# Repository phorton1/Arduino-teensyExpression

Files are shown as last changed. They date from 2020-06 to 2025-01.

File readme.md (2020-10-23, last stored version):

# teensyExpression MIDI controller

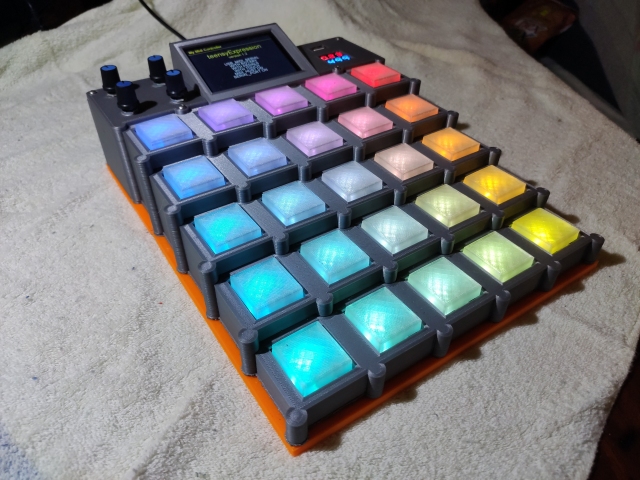
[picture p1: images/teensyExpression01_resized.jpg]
teensyExpression MIDI controller


This github repository describes and contains the source code and other materials
for a 3D printed, **teensy 3.6** based MIDI controller.  The controller has a 5x5 array
of switches, each with an individually adressable ws2812B colored LED,
four rotary controllers,
a 3.5" touchscreen,
inputs for four (4) standard 1/4" expression pedals, a 1/8" stereo jack used for a serial port, and the main USB type "A" connector,
a USB host port, and, lol, a volt/amp meter to monitor the USB power supply.

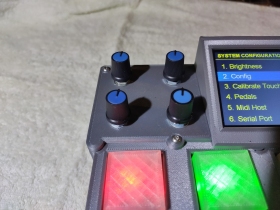
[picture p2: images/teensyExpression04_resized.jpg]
teensyExpression rotary controls

*four rotary controllers*

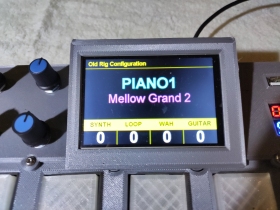
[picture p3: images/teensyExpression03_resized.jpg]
teensyExpression touch screen

*3.5" touchscreen*

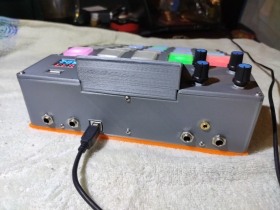
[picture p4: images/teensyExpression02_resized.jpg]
teensyExpression back panel

*inputs for four (4) standard 1/4" expression pedals, 1/8" stereo jack for serial port, and the main USB type "A" connector*

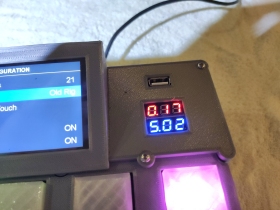
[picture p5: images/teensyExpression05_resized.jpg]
teensyExpression host port and amp-meter

*USB host port, and volt/amp meter on USB power supply*

It is intended to be a *foot* controller ... hence the tiered setup which makes it
easier to press buttons with your toes without having to reach over other buttons.
FWIW, I play the guitar barefooted, while sitting in a chair.

There are two major aspects to this project.  First there is the [**hardware**](hardware/), which is
relatively straight forward, and there are circuit diagrams, fusion 360 files, some
instructions, and so on that might allow someone to create a copy if they wanted to.

The second major aspect is the [**software**](design/). Inasmuch as this was conceived as BOTH an
experimental platform to let me mess with USB midi, and particularly the **Fishman FTP
Triple Play** dongle/controller, it also has been programmed to fit into my existing
performance setup.  For me, it is "gig ready", as well as a place I can try different
experiments with various things.

The software does not present itself as a general purpose, commercially viable,
consumer product.  Though that could be done, it is not my primary focus. So, while
I would be able to create, for example, a box on which the end user could map the
buttons to various MIDI CC control messages at "run time", that is not currently
implemented.

Because the entire thing can be (fairly) easily programmed from the Arduino IDE,
at this time I am selfishly doing whatever the heck I want in C++.   Some stuff
has been modularized and incorporated into things like a system configuration "preferences"
page, with persistent values stored in EEPROM, other stuff is "hard coded" into the C++, an
approach which limits the use of this by less technically saavy "consumer" or "nubie"
readers and potential users.

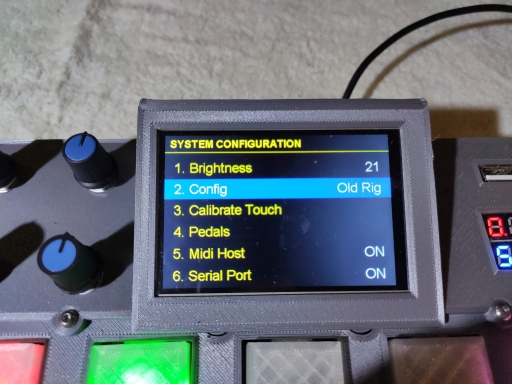
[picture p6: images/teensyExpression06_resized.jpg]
early preferences page


That's what it is.

There is still, in my opinion, considerable value in making this public, and so,
here, in spite of ongoing development, I am creating a public github
repository so that I can present it to you.

## THIS Repository Organization

The following subfolders are considered "public":

* [teensyExpression/](teensyExpression/) - contains the C++ source code,
  including the main INO file (teensyExpression.ino) and the C++ and H files
  needed to build the program.
* [design/](design/) - contains a description of the software architecture,
  with ideas on how other programmers might extend it, along with a
  description of the [User Interface](design/readme_ui.md) in it's
  current incarnation, including the [songMachine](design/readme_songmachine.md)
* [hardware/](hardware/) - contains the basic schematic, circuit diagrams,
  and information about building the electronics portion of the project.
* [ftp/](ftp/) - contains separate discussions and documents regarding
   my reverse engineering efforts on the FTP Triple Play dongle and controller

There are a number of other sub-folders which are considered "private" for my own
personal use, and/or which exist only to support the readme.md files in the this
and the above subfolders:

* **images** - contains images used on this and various readme pages
* **junk** - contains a variety of weird files, images, doc files, that, for me, pertain
      to the design of the project, but which are not meant to be necessrily useful
      for a reader or anyone besides myself.
* **tests** - contains a number of test programs that are not necessarily currently up-to-date
    or useful.  I keep these for posterities sake as they may have snippets of code I will
    need in the future.

### 3D Printing Information

There is a separate repository containing the Fusion 360, STL, and gcode files
for this project that were used to 3D print the box and buttons.

* [fusion/](https://github.com/phorton1/Arduino-teensyExpression-fusion) - contains the STL, fusion 360 files, and notes on how to print and assemble the box

### Please See

This teensyExpression pedal is intimately involved with my long term ongoing
**[rPi bare metal vGuitar rig](https://hackaday.io/project/165696-rpi-bare-metal-vguitar-rig)**
project at hackaday.

In that process I have developed a number of other repositories which might be of interest
to audio system development hackers, including:

* **[circle](https://github.com/phorton1/circle)** - my fork of a a C++ bare metal rPi
development framework
* **[circle-prh](https://github.com/phorton1/circle-prh)** - my extensions to Circle, including
a port of the **Teensy Audio Library** to rPi bare metal, and an Arduino like development
approach.
* **[Loooper](https://github.com/phorton1/circle-prh-apps-Looper)** - a bare metal rPi based **Audio Looper**
including a 3D printed case with a 7" touchscreen, which hooks up to, and is controlled by,
this teensyExpression pedal.

### Notes on Building and GitHub **DEPENDENCIES**

This project relies on the teensyDuino installation.

It also depends on a number of Arduino libraries that must be manually placed in your
Arduino/libraries folder.  There is one small library that I wrote (myDebug.h and myDebug.cpp),
that I generally use in my Arduino programs, and is common to more than one of my published projects.

In addition there are several libraries that are publicly available, but unchanged by me
(ILI9341_t3 and ILI9341_fonts), which I have forked into my github account for ease in finding them,
and to provide me with a stable known "snapshot" of those libraries.

And finally there are some libraries that are publicly available, but to which I
have made modifications to, small or large, in order to get them to work in this project
(Paul's USBHost_t36 and my_LCDWIKI_*).

Each of these libraries is available as a github project here in my account, with a
name that is formatted like "Arduino-libraries-NameOfLibrary".   **These libraries
should be "cloned" or otherwise copied into your Arduino/libraries folder**.  Once
you have done that, you may rename them to remove the "Arduino-libraries" portion,
just leaving the NameOfLibrary portion in the directory structure if you wish.

* [myDebug](https://github.com/phorton1/Arduino-libraries-myDebug) -
   A debugging output library common to my Arduino projects, it contains
   global methods with names like "display" and "display_bytes" which are called
   throughout my code, and which can be turned on or off via defines.

* [base64](https://github.com/phorton1/Arduino-libraries-base64) -
  UNMODIFIED fork of Adam Rudd's https://github.com/adamvr/arduino-base64 repository

* [ILI9341_t3](https://github.com/phorton1/Arduino-libraries-ILI9341_t3) and
  [ILI9341_fonts](https://github.com/phorton1/Arduino-libraries-ILI9341_fonts) -
  These are UNMODIFIED versions of Paul's ILI9341 libraries, forked from
  his repository on 2020-10-03.   My program *may* compile and work with
  more current versions that he makes available at https://github.com/PaulStoffregen/ILI9341_t3
  and https://github.com/PaulStoffregen/ILI9341_fonts, but these forks are
  known to compile and work properly with my code.

* [USBHost_t36](https://github.com/phorton1/Arduino-libraries-USBHost_t36) -
  A slightly MODIFIED version of Paul's USBHost_t36 library, forked
  from https://github.com/PaulStoffregen/USBHost_t36 on 2020-10-03.
  The API was changed to make a few functions virtual and to expose
  a few private variables as "protected".

* [SdFat](https://github.com/phorton1/Arduino-libraries-SdFat) -
  A fork of Bill Greiman's https://github.com/greiman/SdFat with one slight
  modification - to increase BUSY_TIMEOUT_MICROS from 500000 to 1000000,
  which fixed problems I was having opening an SD card on a fresh boot.

* [my_LCDWIKI_GUI](https://github.com/phorton1/Arduino-libraries-my_LCDWIKI_GUI),
  [my_LCDWIKI_KBV](https://github.com/phorton1/Arduino-libraries-my_LCDWIKI_KBV), and
  [my_LCDWIKI_TouchScreen](https://github.com/phorton1/Arduino-libraries-my_LCDWIKI_TouchScreen) -
  These repositories contain the rude and crude port of the LCDWIKI Arduino libraries
  to the Teensy for the cheap touch screen I ended up using.  The touch screen
  is an 8 bit parellel port screen that looks like this:

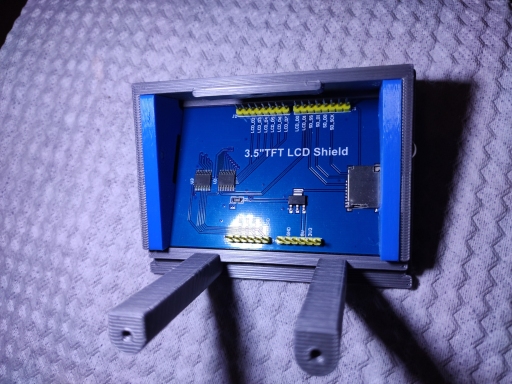
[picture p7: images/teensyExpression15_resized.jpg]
touchscreen holder
  

When I started working on this project, I started off using a different, much
faster and more teensy compatible 2.8" SPI touch screen.  One night I burned it, and
because I did not want to wait 6 weeks for a replacement (I live on a remote
island in the tropics) I was forced to go to a slower speed 8 bit parallel
Arduino touch screen ... which in turn required me to port the LCDWIKI library
for it to the teensy 3.6, which I did.

# Credits

Pretty much everything I do has been tremendously influenced by, and is more or less a direct
result of the work done by **Paul Stoffregen** and his wonderful **teensy** series of MPU boards.

Please visit his website at [prjc.com](https://www.prjc.com) and support him by purchasing teensy
boards and teensy related parts and accessories.    He also has github, hackaday, and facebook pages
that you can find easily on the internet. The man's a giant to me, and has forged important new
ground not only with the boards he makes, but also with the **vast** amount of open source
software he has created, not the least of which includes the ws2812 and ili9431 libraries, but
also his audio library, and well, what can you say ... so much more!

Also thanks to the many folks who have contributed to the [lcdwiki](http://www.lcdwiki.com) project.
Though I can't name them by name, many are the times when I have visited their website and utilized
their code.

That's it!

Thanks for checking this out!

Updated October 2020 - Patrick

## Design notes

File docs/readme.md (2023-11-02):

# teensyExpression MIDI controller



This github repository describes and contains the source code and other materials
for a 3D printed, **teensy 3.6** based MIDI controller.  The controller has a 5x5 array
of switches, each with an individually adressable ws2812B colored LED,
four rotary controllers,
a 3.5" touchscreen,
inputs for four (4) standard 1/4" expression pedals, a 1/8" stereo jack used for a serial port, and the main USB type "A" connector,
a USB host port, and, lol, a volt/amp meter to monitor the USB power supply.


*four rotary controllers*


*3.5" touchscreen*


*inputs for four (4) standard 1/4" expression pedals, 1/8" stereo jack for serial port, and the main USB type "A" connector*


*USB host port, and volt/amp meter on USB power supply*

It is intended to be a *foot* controller ... hence the tiered setup which makes it
easier to press buttons with your toes without having to reach over other buttons.
FWIW, I play the guitar barefooted, while sitting in a chair.

There are two major aspects to this project.  First there is the [**hardware**](hardware.md), which is
relatively straight forward, and there are circuit diagrams, fusion 360 files, some
instructions, and so on that might allow someone to create a copy if they wanted to.

The second major aspect is the [**software**](design.md). Inasmuch as this was conceived as BOTH an
experimental platform to let me mess with USB midi, and particularly the **Fishman FTP
Triple Play** dongle/controller, it also has been programmed to fit into my existing
performance setup.  For me, it is "gig ready", as well as a place I can try different
experiments with various things.

The software does not present itself as a general purpose, commercially viable,
consumer product.  Though that could be done, it is not my primary focus. So, while
I would be able to create, for example, a box on which the end user could map the
buttons to various MIDI CC control messages at "run time", that is not currently
implemented.

Because the entire thing can be (fairly) easily programmed from the Arduino IDE,
at this time I am selfishly doing whatever the heck I want in C++.   Some stuff
has been modularized and incorporated into things like a system configuration "preferences"
page, with persistent values stored in EEPROM, other stuff is "hard coded" into the C++, an
approach which limits the use of this by less technically saavy "consumer" or "nubie"
readers and potential users.



That's what it is.

There is still, in my opinion, considerable value in making this public, and so,
here, in spite of ongoing development, I am creating a public github
repository so that I can present it to you.

## THIS Repository Organization

TODO: rework this whole section

This repository contains the C++ source code,
  including the main INO file (teensyExpression.ino) and the C++ and H files
  needed to build the program.

There are a number of other sub-folders which are considered "private" for my own
personal use, and/or which exist only to support the readme.md files in the this
and the above subfolders:

* **images** - contains images used on this and various readme pages
* **junk** - contains a variety of weird files, images, doc files, that, for me, pertain
      to the design of the project, but which are not meant to be necessrily useful
      for a reader or anyone besides myself.
* **tests** - contains a number of test programs that are not necessarily currently up-to-date
    or useful.  I keep these for posterities sake as they may have snippets of code I will
    need in the future.

### 3D Printing Information

There is a separate repository containing the Fusion 360, STL, and gcode files
for this project that were used to 3D print the box and buttons.

TODO: rework

### Please See

This teensyExpression pedal is intimately involved with my long term ongoing
**[rPi bare metal vGuitar rig](https://hackaday.io/project/165696-rpi-bare-metal-vguitar-rig)**
project at hackaday.

In that process I have developed a number of other repositories which might be of interest
to audio system development hackers, including:

* **[circle](https://github.com/phorton1/circle)** - my fork of a a C++ bare metal rPi
development framework
* **[circle-prh](https://github.com/phorton1/circle-prh)** - my extensions to Circle, including
a port of the **Teensy Audio Library** to rPi bare metal, and an Arduino like development
approach.
* **[Loooper](https://github.com/phorton1/circle-prh-apps-Looper)** - a bare metal rPi based **Audio Looper**
including a 3D printed case with a 7" touchscreen, which hooks up to, and is controlled by,
this teensyExpression pedal.

### Notes on Building and GitHub **DEPENDENCIES**

This project relies on the teensyDuino installation.

It also depends on a number of Arduino libraries that must be manually placed in your
Arduino/libraries folder.  There is one small library that I wrote (myDebug.h and myDebug.cpp),
that I generally use in my Arduino programs, and is common to more than one of my published projects.

In addition there are several libraries that are publicly available, but unchanged by me
(ILI9341_t3 and ILI9341_fonts), which I have forked into my github account for ease in finding them,
and to provide me with a stable known "snapshot" of those libraries.

And finally there are some libraries that are publicly available, but to which I
have made modifications to, small or large, in order to get them to work in this project
(Paul's USBHost_t36 and my_LCDWIKI_*).

Each of these libraries is available as a github project here in my account, with a
name that is formatted like "Arduino-libraries-NameOfLibrary".   **These libraries
should be "cloned" or otherwise copied into your Arduino/libraries folder**.  Once
you have done that, you may rename them to remove the "Arduino-libraries" portion,
just leaving the NameOfLibrary portion in the directory structure if you wish.

* [myDebug](https://github.com/phorton1/Arduino-libraries-myDebug) -
   A debugging output library common to my Arduino projects, it contains
   global methods with names like "display" and "display_bytes" which are called
   throughout my code, and which can be turned on or off via defines.

TODO: cleanup NEEDS vs USES forked libraries

* **base64** -
  UNMODIFIED fork of Adam Rudd's https://github.com/adamvr/arduino-base64 repository
* [ILI9341_t3](https://github.com/phorton1/Arduino-libraries-ILI9341_t3) and
  [ILI9341_fonts](https://github.com/phorton1/Arduino-libraries-ILI9341_fonts) -
  These are UNMODIFIED versions of Paul's ILI9341 libraries, forked from
  his repository on 2020-10-03.   My program *may* compile and work with
  more current versions that he makes available at https://github.com/PaulStoffregen/ILI9341_t3
  and https://github.com/PaulStoffregen/ILI9341_fonts, but these forks are
  known to compile and work properly with my code.

* [USBHost_t36](https://github.com/phorton1/Arduino-libraries-USBHost_t36) -
  A slightly MODIFIED version of Paul's USBHost_t36 library, forked
  from https://github.com/PaulStoffregen/USBHost_t36 on 2020-10-03.
  The API was changed to make a few functions virtual and to expose
  a few private variables as "protected".

* [SdFat](https://github.com/phorton1/Arduino-libraries-SdFat) -
  A fork of Bill Greiman's https://github.com/greiman/SdFat with one slight
  modification - to increase BUSY_TIMEOUT_MICROS from 500000 to 1000000,
  which fixed problems I was having opening an SD card on a fresh boot.

* [my_LCDWIKI_GUI](https://github.com/phorton1/Arduino-libraries-my_LCDWIKI_GUI),
  [my_LCDWIKI_KBV](https://github.com/phorton1/Arduino-libraries-my_LCDWIKI_KBV), and
  [my_LCDWIKI_TouchScreen](https://github.com/phorton1/Arduino-libraries-my_LCDWIKI_TouchScreen) -
  These repositories contain the rude and crude port of the LCDWIKI Arduino libraries
  to the Teensy for the cheap touch screen I ended up using.  The touch screen
  is an 8 bit parellel port screen that looks like this:

  

When I started working on this project, I started off using a different, much
faster and more teensy compatible 2.8" SPI touch screen.  One night I burned it, and
because I did not want to wait 6 weeks for a replacement (I live on a remote
island in the tropics) I was forced to go to a slower speed 8 bit parallel
Arduino touch screen ... which in turn required me to port the LCDWIKI library
for it to the teensy 3.6, which I did.

# Credits

Pretty much everything I do has been tremendously influenced by, and is more or less a direct
result of the work done by **Paul Stoffregen** and his wonderful **teensy** series of MPU boards.

Please visit his website at [prjc.com](https://www.prjc.com) and support him by purchasing teensy
boards and teensy related parts and accessories.    He also has github, hackaday, and facebook pages
that you can find easily on the internet. The man's a giant to me, and has forged important new
ground not only with the boards he makes, but also with the **vast** amount of open source
software he has created, not the least of which includes the ws2812 and ili9431 libraries, but
also his audio library, and well, what can you say ... so much more!

Also thanks to the many folks who have contributed to the [lcdwiki](http://www.lcdwiki.com) project.
Though I can't name them by name, many are the times when I have visited their website and utilized
their code.

That's it!

Thanks for checking this out!

Updated October 2020 - Patrick

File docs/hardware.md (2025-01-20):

# Hardware (Electronics)

This subfolder contains the basic electrical circuit details used
in building the teensyExpression Box.

Physically, the most demanding task was to build the **switch array**, with 25 little
circuit boards, and 25 LED's to connect together in a grid.  Each LED is connected into
a series by 3 wires ... in two directions ... ground, 5V, and data in / data out from the
first, to the last LED.  A single 3 pin connector connects all 25 LED's to the teensy
(motherboard) and power supply.

The switch harness, overlayed on top of LED serial connections, consists of the 25
buttons connected (soldered) together into a 5x5 grid that presents itself
as two 5 pin connectors to the *motherboard*.

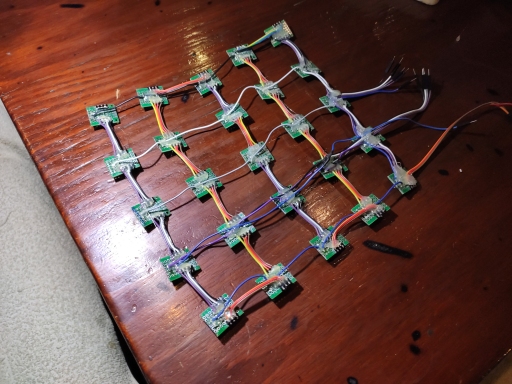
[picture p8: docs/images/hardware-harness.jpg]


The **motherboard** is a 70x50 mm prototype board that has a socket (two rows
of female header strips) into which a teensy 3.6 is plugged,
and which has connectors (female header strips) for the LEDs, switches,
rotary controls, serial port, TFT LCD display. The host USB port connector
is on the teensy 3.6 board itself.

Virtually every pin on the teensy was used in this
exersize, at the sacrifice of future expandability, but the gain of simplicity in the
circuit design.  Previous design iterations had used IO multiplexer chips, for example,
to communicate with the swtich array, via 4 pins, instead of 10, but in the end I just
decided to let the teensy handle all 10 pins from the switch array in favor of a simpler
electronic circuit.

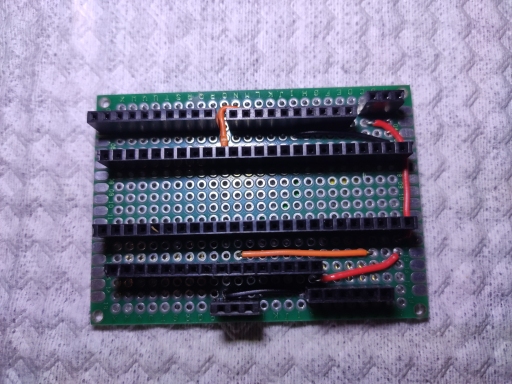
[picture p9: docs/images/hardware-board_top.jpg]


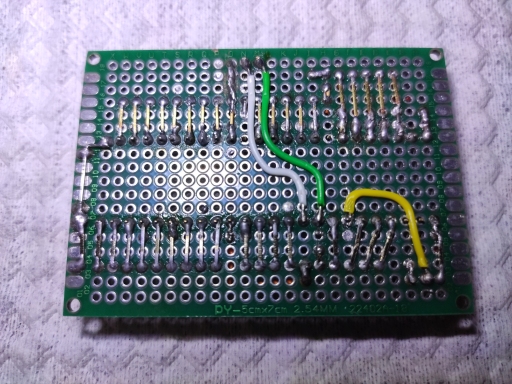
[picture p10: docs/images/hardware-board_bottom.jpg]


The TFT/touchscreen is connected to the motherboard through two 8 pin connectors.

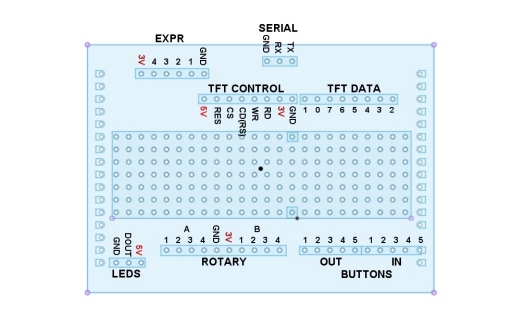
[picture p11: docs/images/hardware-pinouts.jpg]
hardware-pinouts,jpg

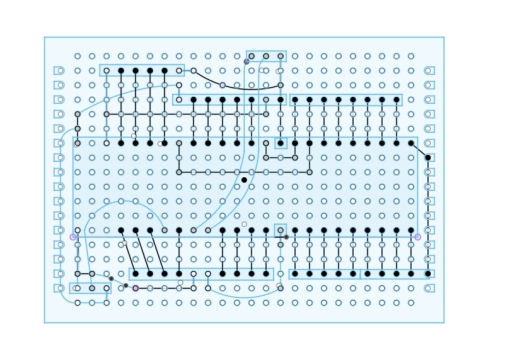
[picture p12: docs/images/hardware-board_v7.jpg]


Besides those three main components, there are separate subassemblies
and/or circuit boards for the four **rotary countrollers**,
the **USB port and amp-meter**, the **serial port connector**, and, finally,
the back panel with it's **four expression pedal 1/4" stereo jack inputs**.

There is a general overall sybolic schematic for this project.
You can click on the image below to see the PDF file.

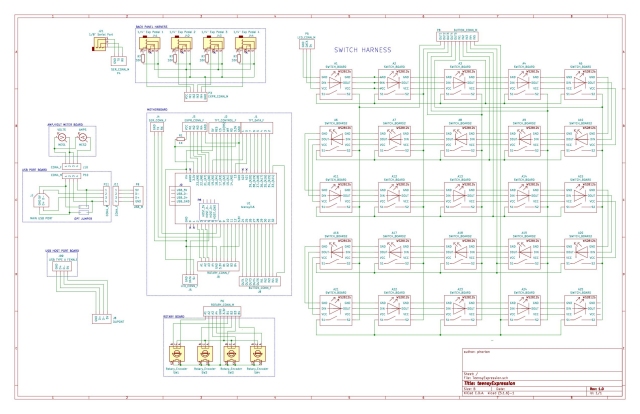
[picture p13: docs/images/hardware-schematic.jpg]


## LED/Switch Array

Each switch array circuit board contains a swtich and a ws2812b addressable LED.
The LEDs are wired back together with three wires between each one, in a series,
starting from the top left position, row-wise, back and forth, so the last LED
is at the bottom right.

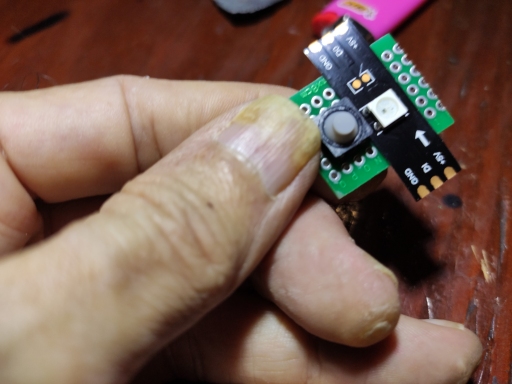
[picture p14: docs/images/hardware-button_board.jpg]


I cut the 25 ws2812 LED's from an inexpensive light strip that can be had for
as little $2, with shipping, on ebay.

The strip I used has 30 LEDs, with 30mm spacing, and with capacitors on about
every 8th LED. So one small strip was sufficient to make the box.

The switch circuit boards were cut to 20x25 mm from commonly available
20x80mm prototype boards that cost about 60 cents each on ebay.  I bought
them as part of a pack which included some other sizes for something
like $8.   With care 3 of switch-boards can be cut from each prototype board,
and, since 25 are needed, you'd need 9 of the prototype boards to reproduce
this project.

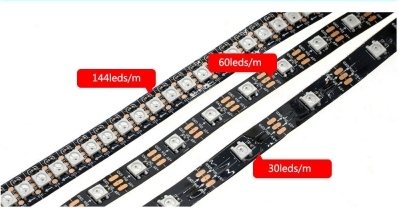
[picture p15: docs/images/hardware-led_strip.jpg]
(https://www.ebay.com/itm/383642094481)

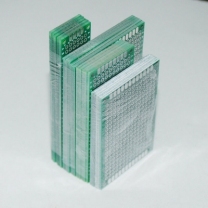
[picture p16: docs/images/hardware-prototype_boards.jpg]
(https://www.ebay.com/itm/252520067657)


*click on images above to see them in ebay*

I had already decided to make the buttons have a 45 mm spacing, a little larger,
and with a little more space than the drum pads on an akai MPD218 (typical
midi drumpad device).   The LED strips have a 30 mm spacing ... and so, after some
consternation ... I opted for the demanding task of cutting the strip apart and
then soldering it back together.

I tried to uniformely distribute the LED capacitors throughout the harness.

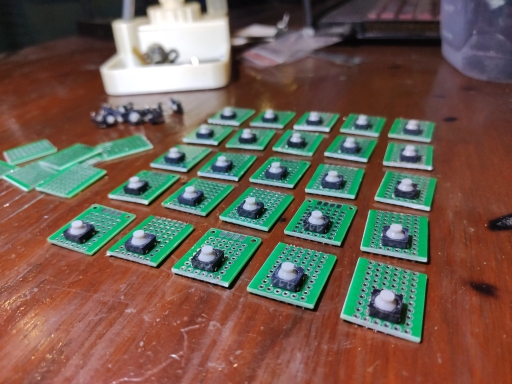
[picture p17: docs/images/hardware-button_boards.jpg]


The switches are soft silicon with momentary contacts.  They seemed to provide
enough spring back to work, and they work fine in practice.   I found them
available on ebay for $1.85 for 20 (so you'd need two packs, but have 15 left
over at the end).

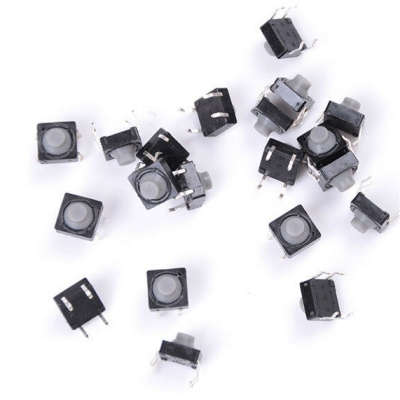
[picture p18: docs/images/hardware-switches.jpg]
(https://www.ebay.com/itm/313082729862)


*click on image above to see in ebay*

To complete the circuit boards I put a drop of super glue on the back of each
LED piece, held it on the circuit board, and bent the connectors around to the
back, trying to keep it as close as possible (centered) to the switch, which
occupies a 2x3 footprint on the board.

The switches are wired together in an array, with columns connnected to one pin of
each switch and rows connected the other pin of each switch.  Rows start at the
top and go down, and columns start at the left and go to the right.  These wires
end in two connectors which are called OUT (columns) and IN (rows) which plug
directly into the motherboard.  If you get em backwards, you merely have to change
the IN and OUT defines in the source code.

## Mother Board

The circuitry on the **motherboard** is pretty simple.  Most of it was
connected by using female headers with long leads and bending the leads
and connecting direclty to another header.

Here are two diagrams that show, respectively, the wiring for the back,
and the front of the circuit board.   The solid lines are made either
by bending leads and soldering them, or by running beads of solder
over multiple holes in the prototype board. The lighter blue lines
are wires that are soldered from one point to another.

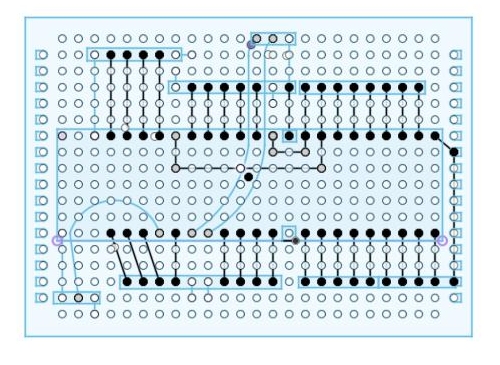
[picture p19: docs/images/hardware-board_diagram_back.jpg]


*above, motherboard back (as seen from the front)*

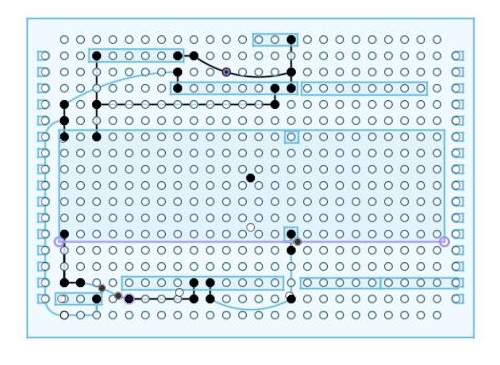
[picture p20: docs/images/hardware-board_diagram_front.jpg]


*above, motherboard front*

## TFT Touch Screen

The Touchscreen is connected directly to the motherboard by two 8 pin
dupont female to male cables.



The pinouts are detailed in previous diagrams.

## Rotary Encoders

I didn't take any pictures, or keep any detailed design description of the
Rotary Encoder board I threw together. So I would have
to open the box up and disassmble it to present it properly.

I am not using the momentary switches on the rotary encoders.
They were kind of an afterthought, and I had no more pins available on
the teensy by that point in the hack/implementation.

As I remember, I did not put any resistors or capacitors on it, I just wired
the ground to the ground pin for the momentary switch (don't even think it'sda
used), the 3.3V to the center pin on the rotary part of the things (the side with
three pins), and the pairs of connectors (IN and OUT) to the left, and right
pins on that side of the things.

If you get it wrong you merely have to change the definitions of the IN
and OUT pins in the source code.

## USB Port and Amp Meter

During earlier prototyping, and in general, I was curious about the power
consumption of the device, and so had taken to using an inexpensive USB
power meter to monitor the power usage.

These power meters are available on Ebay for about $7.

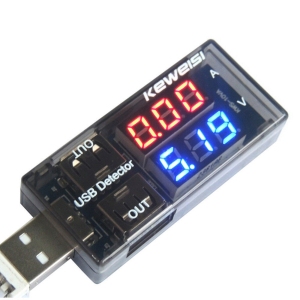
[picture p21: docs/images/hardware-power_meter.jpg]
(https://www.ebay.com/itm/401708239662)


*click on the image to go to ebay*

I merely desoldered the USB connectors, and connected the ground and 5V from
the main input USB typeB port to it, and ran it back to the micro-usb connnector
that connects to the teensy.

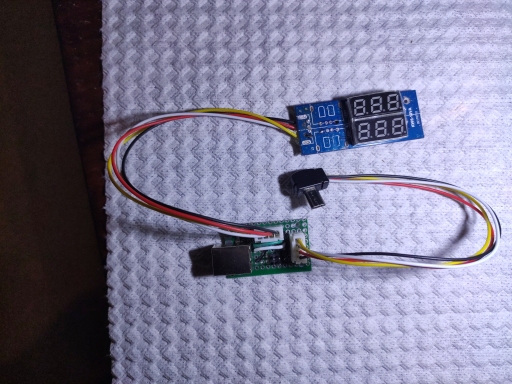
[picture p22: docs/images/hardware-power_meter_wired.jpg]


I was very pleased with these little micro-usb connectors that I also got
on ebay, at 10 for $5.79 (about 60 cents each)

And I needed the female TypeB connector as well (probably around $1 on ebay).

What made this step considerably more fun, and easy, was the purchase of some
prewired headers and sockets for 2.54mm circuit boards.  I got 10 of em for
under $4 on ebay, and used to two in this project.  I will definitely use these
more in the future, as I **hate** dupont connectors and trying to build them
from scratch!

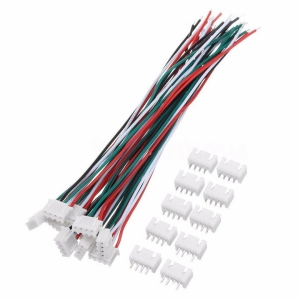
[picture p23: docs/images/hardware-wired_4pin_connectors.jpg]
(https://www.ebay.com/itm/264781666854)


The circuit board  is approximately 24x38 mm, and the typeB USB connector
projects about 3mm through the back of the box.

But it's really simple.  Basically it connects the typeB female usb port ground and 5V
to an outgoing pair on the connector that goes to the power meter, and the incoming pair
that comes back and is connected to the ground and 5V pins on the outgoing (to
the teensy) micro-usb connector.

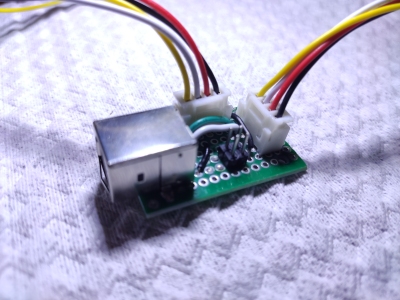
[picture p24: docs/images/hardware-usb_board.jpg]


The D- and D+ pins from the typeB connector are wired directly to the
output connector, and I added a jumper so that, if I want, I can remove
the USB meter and jumper the 5V and ground directly from the input typeB
socket to the output micro-usb connector.

Sorry about the lack of detail here! I am writing this *after* I finished
the hardware aspects of the project, but I think you can figure out how
it goes from this, and other standard information available on the web
about USB connectors.

## Serial Port Connector

The serial port connector is merely a 1/8" stereo jack connected
to a 3 pin dupont connector.   The *tip* of the connector is the
RX into the teensy, the *ring* is the TX from the the teensy, and
the *sleeve* is the ground.

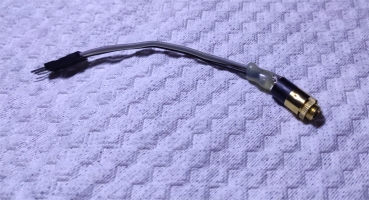
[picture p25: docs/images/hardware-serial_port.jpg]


The female, gold plated, 1/8 stero jack was about $1.50 on ebay.

## Host Port USB connector/board

The host port USB connector board is another 24x20 mm piece of one of the
20x80 prototype boards, with a micro USB female connector at one end, and
a 4 pin dupont connector at the other, that connects to a 4 pin header
soldered onto the teensy 3.6 board.

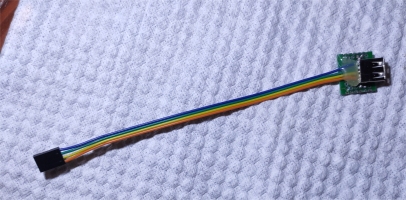
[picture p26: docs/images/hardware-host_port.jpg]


The female micro USB connectors are about 30 cents each, when purchased in
lots of 10 on ebay.

## Back Panel and 1/4" Expression Jacks

That leaves the back panel and the four 1/4" expression jacks.

I attached these to the 3D printed back and soldered the wires on in place so-as
to get appropriate lengths of wire with a minimum of fuss.   They are wired with
ground going to the *sleeve* of each connector, 3.3V going to the *ring*, and
the return "sense" pin wired to the *tip*.   The jacks were probably about $1
each on ebay.

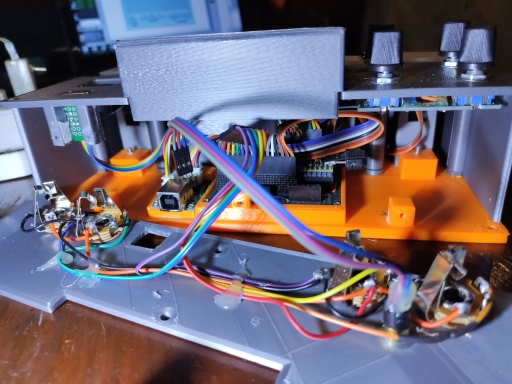
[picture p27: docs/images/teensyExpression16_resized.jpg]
putting it together1


After I put it together, I ran into some problems with this part of the build.
Notably, that when you would plug a 1/4" jack into the the things, it would
momentarily short the 3.3V to ground, yikes, rebooting the system.

It is not a good idea to short the 3.3V output from the voltage regulator
on the teensy directly to ground!

Yet I think the connectors are actually designed to avoid doing that by the spacing
of the tip and ring parts of the male vs the contact points of the female jacks.

The final solution was that I put a 1K resistor on the motherboard between the
3.3V output from the teensy and the common 3.3V connectors (*rings*) on the
connectors.   Although that works, by limiting the current that can flow in
the event of a short circuit, it should not have been necessary and I am
still thinking about how to do it correctly (next time!).

# Cost of Electronics Summary

So, as a curiousity, after the fact, I have tallied up the following costs for the
electronics part of the build.   Clearly the most expensive items is the teensy 3.6,
which I got WITH pins from  at: [prjc.com](https://www.pjrc.com/store/teensy36_pins.html).
They are currently $33.25.  Some of the other costs are just estimates, but I think its
pretty close.

| item | price |
|---|---|
| Teensy 3.6 pins |  $33.25 |
| USB Power Meter | $7.00 |
| 3.5" Touch Screen |  $5.00 |
| 30 x LED ws2812b strip | $2.00 |
| 25 x push buttons | $2.50 |
| 4 x Rotary Encoder | $4.00 |
| 4 x 1/4" female jacks | $5.00 |
| 1/8" female jack | $1.25 |
| female micro USB connector | $0.50 |
| mother prototype board | $2.50 |
| rotary encoder prototype board | $2.50 |
| 10 x small prototype boards | $10.00 (max) |
| Wired connectors and jacks | $1.00 |
| 5 x 40 pin female headers | $2.50 |
| Wired Dupont Connectors | $4.00 (max) |
| Other Wire | $1.00 |
| Solder, etc | $1.50 |
| **Total** | approx **$85.50** |

It was my goal to try to keep the cost of the project at, about, or under **$100**.
If I figure I used about 1kg of plastic in 3D printing it, at $20/kg,
then, I came close. This box could theoretically be built by anyone with a
3D printer for about $110.

Though I doubt anyone will take my exact design and replicate it, apart
from wanting the box itself, I wanted to prove that it could be made on
a budget, if one is willing to put the effort into it.

Also note that you could eliminate stuff (like the rotary encoders
and the usb power meter) in order to cut the costs a bit. I don't
actually envision using the rotary controllers that much as it is
a floor based *foot* pedal.

For me it is replacing a $270 Softstep II, a $100 akai MPD218, and
a $170 audio-front expression-to-usb-midi convertor, or nearly $600
of gear ... and three separate devices ... with one consolidated
usb midi device, so in addition to cost factors, for me it also reduces
the complexity of my rig, and the setup and teardown times thereof.

It also provides me with much more flexibility to do what I want, and
have not even yet envisioned, going forward.  More on that in the
software section of the project.

I have not seen any comparable hardware that sells for less than $200.
In fact, a box similar to this would probably retail in the $400-$500
price range, and some go for as much as $1500 to $2000.
I couldn't find what I wanted in the way of a foot controller
for running the FTP in conjunction with SampleTank and Tonestack
on Audiobus, on an iPad, so I built this.

Of course, it took several weeks of 3D design work, prototyping, and
nearly 2 full 40 hour weeks for me just to consctruct the final prototype.
And I'll probably be working on the software for months, or mabye years, more.
Nonetheless, it *might* be something that a typically impoverished musician could
put together.

So, with that, I conclude the "hardware" portion of our show!

Thanks,

**Patrick**

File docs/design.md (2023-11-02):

# Design (Software Architcture)

This page describes the software architecture for the teensyExpression ino
program.

For a discussion of the user interface (the "user manual"), please see
the [User Interface](ui.md) readme file.

For a discussion of the advanced automation features of the device,
please see the [songMachine](songmachine.md) readme file.

## Basic Architecture

The system can be viewed as a series of "layers", generally increasing in level
of abstraction as you move up the following diagram:

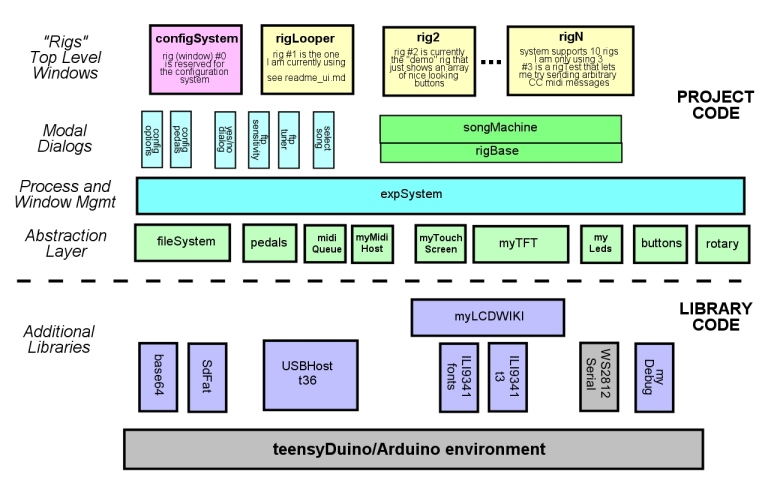
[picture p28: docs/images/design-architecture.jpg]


Everything above the dashed line, the **Project Code**, can be found in this repository.

Everything below the dashed line is in the *Arduino/libraries* folder (blue boxes) in
separate repositories available on my github page, and linked to from the main readme.md
file, or are (grey boxes) part of the basic **teensyDuino/Arduino** development environment
and easily available for public download.

Above the dashed line, the *teensyExpression* code, is organized somewhat as
follows.  There are a number of APIs (classes, objects) that represent an
**abstraction layer** of common functionality that are generally available to
higher layers.   This includes

- an abstraction of the SD Card FAT32 **fileSystem**.  The file system
  has it's own readme file at [filesystem.md](filesystem.md).
- an object that manages the four expression **pedals**
  including polling them and their functional behavior
- objects to process, and monitor **MIDI** io, including a
  *queue*, and handling both the main teensyDuino *USB midi* port,
  as well as the teensy 3.6 *midiHost* port
- a thin layer of abstraction of the **TouchScreen** and **TFT** display devices
- management of the ws2812 **LEDs**
- an object to manage and work with the 5x5 array of **buttons**
- an object to manage the **rotary controllers**

Above that, the **expSystem** is the main active object in the system.
It initializes all of the subsystems and does the bulk of event management,
in one of three ways: either by being called directly from the
teensyExpression.ino loop() method, or via one of two timer
interrupts:

- **updateUI()** is called directly from the main INO *loop()* method.
  This is the "UI thread" and is not considered time critical. All
  redrawing of the screen, and most updating of the LED colors,
  as well as certain processing of non-critical events happens
  in updateUI().
- **criticalTimerHandler()** is called up to 1000 times per second
  and handles the most time critical task, which is to
  transfer incoming midi from the midi-host port to the main USB
  midi port as rapidly as possible for live peformance.
  It also generally enqueues all midi
  messages for further processing and toggles the midi-activity
  indicator states for re-display in *updateUI()*.
- **timerHandler()** is called up to 200 times per second and
  does the bulk of the work in the system, including calling
  methods to poll the *pedals* and *buttons*, process the *serial
  ports* for incoming serial midi or file system traffic, and
  to process the *midiQueue* for midi monitoring and (FTP and
  external Looper) state changes.

Above the expSystem you have the main **Top Level Windows"** in
the system, which I call **"rigs"**.  There can only be one currently
active "rig" at a time, and those windows ALSO can implement
virtual versions of the *updateUI()*, *criticalTimerHandler(),* and
*timerHandler()* methods as they see fit.

Top Level Windows also get abstracted events from the expSystem
via the following virtual method calls:

- virtual bool **onRotaryEvent**(int num, int val)
- virtual void **onButtonEvent**(int row, int col, int event)
- virtual void **onSerialMidiEvent**(int cc_num, int value)

We will discuss **Rigs (Top Level Windows)** in more detail, below.

Finally, the expSystem manages various **modal dialog windows** that
can be popped (stacked) up over a given Top Level window.  Modal dialogs
can (and do) reprogram the buttons and LED colors as they see fit.
These modal windows include, at least conceptually, the following:

- **configOptions**, though not really windows, these are abstractions of
   configurable options that have a UI, and are stored as "preferences"
   (prefs.h) in EEPROM, and are managed by the **configSystem** (rig #0).
- **winConfigPedal** is a modal dialog that lets you edit the configuration
   of one of the four expression pedals, setting the basic *pedal type*,
   and within that one of three *curve types*, and the *curve points*
   that make up the curves.

The above are ONLY used by the configSystem.
The following are available for general use withing Rigs:

- **yesNoDialog** is a general purpose dialog to ask a question and get
  a yes/no (0/1) response.
- **winFtpSensitivity** is a modal dialog that allows you to display
  and adjust the sensitivity of the Fishman Triple Play pickup.
- **winFtpTuner** is a modal dialog that implements a guitar tuner
  using the Fishman Triple Play pickup.  It shows a "live" guitar
  fretboard, and typical guitar tuner UI.
- **winSelectSong** is a modal dialog that lets you choose, and/or
  view a **song file** which will run in the **songMachine**.
  The songMachine will also be discussed in more detail below,
  and in a separate readme file.

## Rigs (Top Level Windows)

The idea behind **"rigs"** is that you can have completely different setups,
that can do completely different things, with completely different user
interfaces and behaviors.

I have, in the past, used Rigs to differentiate, for instance, between
a tested, and gig ready piece of code, and another in-progress experimental
approach to some given hardware.

As currently checked-in (implemented) **I am only making use of one
actual functioning "rig"**.  I call this the **"LooperRig"** (*rigLooper.h
and cpp*), and it will provide the basic example, and documentation,
of "how the teensyExpression works" at this time.

The checked in source code *DOES* include two other "rigs".  One is
a **"demo" rig** that does nothing more than set all 25 leds to a nice
set of colors (as seen in the main photos of the pedal), and the other
is a vestigial piece of code, a **"test" rig**, that I created at one point
to allow me to send arbitrary MIDI CC messages and values to devices
for testing purposes.

Finally, it is important to note that the **"configSystem"** that
lets you modify, and retain settings through re-boots via "preferences"
stored in EEPROM, is implemented as rig #0, and so **rig number (0)
is reserved** and there is some special handling in expSystem.cpp
related to it, namely that *the top right button of every rig is
automatically set by the expSystem to "go to" the configuration
system (rig 0) on a **LONG CLICK***.

Apart from that, a rig "takes over" all of the buttons, LED display
characteristics, most of the display, and can have any arbitrarily
defined behavior.

## configurationSystem and rigLooper

A description of the user interface of these two rigs, which
currently pretty much constitutes the entire user interface at
this time can be found in the [User Interface](ui.md) readme file.

## songMachine and rigBase

The main Looper Rig (rigLooper.h and cpp) derives from **rigBase**.
Top Level windows that derive from *rigBase* can interact with,
and be driven by the **songMachine**.

The *songMachine* is an interpreter that takes text files that
describe a state machine that can be used to further automate
and orchestrate complicated tasks.

For example, the Looper Rig is capable of allowing you to
choose, in real time, a given *Synthesizer patch* vis one
set of buttons, or to turn a given *guitar effect* on or off
via another set of buttons, and/or *control the looper*
via a third set of buttons.

So, in a typical example, you might select the "Bass"
synthesizer patch with one button, turn the guitar down
and the synthesizer up with the pedals, and then press
a button to trigger a loop to start recording.

In this *"realtime"* mode of using the pedal, it can turn
out that you spend all your time **looking at your feet!**
And that there are **complex** series of buttons you must
press to orchestrate a given live-looped song.  It can
also be very difficult to do things like "dial in" volume levels
via the expression pedals on the fly, say, for example,
if you want to mix the guitar with the synth in just a
certain way.

What I have found is that what you really want,
in a given song, at a certain time, is to change a
number of things, all at once, and that, in fact, all
you are really need to do, are doing, for a given song
structure, is providing *timing cues* as to **WHEN**
you want something to happen.

The songMachine allows the user to "program" the
*track1-4* buttons (it *"takes over"* the bottom left four
buttons of the teensyExpression pedal, which are normally
the Looper *track1-4* buttons in the Looper Rig)
to whatever color is desired, and to have virtually
any behavior available in the system.

The provided **text file** (program) then tells the machine
how to use those four buttons, and *"loop events"* to work
with the Synth, Guitar Effects, and Looper, devices, sending
out MIDI event to effect and orchestrate complicated behaviors
at gig time,
**without needing complicated series of (foot) button presses**
or pedal changes to accomplish them.

Typically an entire song can be orchestrated through
3 or 4 presses of a single button, which allows the player
to concentrate on their performance ... and not on their feet!

The songMachine is also granted dedicated real estate
on the TFT screen to show the name and status of the
currently playing song, as well as two user-programmable
display areas.

Here is a short snippet of **"songmachine code"** that
may serve as an example.  Hopefully the comments are descriptive.

``` ruby
# INTRO and CHORUS 0

    # the program is executed from the beginning of the file
    # as soon as the song is "loaded"

    start:
        CLEAR_LOOPER                    # clear the looper to start
        LOOP_VOLUME 63                  # set looper to a known volume
        SYNTH_VOLUME 0                  # turn the synth all the way down
        GUITAR_VOLUME 70                # set the guitar to a known volume
        SYNTH_PATCH Bass1               # pick a synth patch for later use
        GUITAR_EFFECT_NONE              # turn off all guitar effects
        BUTTON_COLOR 4,yellow           # make 4th button from bottom left yellow
        BUTTON_COLOR 1,orange,FLASH     # make the first button flashing orange
        DISPLAY 1,"INTRO"               # display the part of the song we are in
        DISPLAY 2,"sing intro"          # display instructions about what to do here

        # the machine "blocks" on button1-4 or loop labels.
        # it advances to the next "buttonN" if that button is
        # pressed, or "loop:" label if the looper cycles through
        # a loop ...

        # In this example you play the intro, and then when ready, press the
        # 1st button to start recording the chorus ....

    button1:                            # when you press button1 the following happens:
        LOOPER_TRACK 1                  # start the looper recording
        BUTTON_COLOR 1,red              # set the button to red to indicate recording
        DISPLAY 1,"CHOR0"               # display the part of the song we are in
        DISPLAY 2,"recording base clip" # display what's going on at this time

# LEAD 0 - Acoustic guitar fill thru base clip

        # once you press the button again, it starts playing the loop,
        # turns on the guitar echo so you can play lead over it ...

    button1:
        LOOPER_TRACK 1                  # end recording
        delay 10                        # 10's of a second to allow for good loop end recording
        GUITAR_EFFECT_ECHO on           # turn on the echo effect
        BUTTON_COLOR 1,green,FLASH      # change button to green flashing
        DISPLAY 1,"A-LEAD"              # display stuff ...
        DISPLAY 2,"play acc lead\nready bass"

        # ready bass - you press this button at the end of the
        # guitar lead but BEFORE the loop happens to fade
        # out the guitar and fade in the bass before recording it.

    button1:                            # press this BEFORE loop ends!
        BUTTON_COLOR 1,red,FLASH        # show red flashing button
        GUITAR_VOLUME 0,20              # bring guitar down over 2 seconds
        SYNTH_VOLUME 85,20              # while bringing synth up over two seconds
        DUB_MODE                        # set dub mode to ...
        LOOPER_TRACK 1                  # start recording on next loop
        DISPLAY 2,"ready record bass"

# VERSE1 and CHORUS1 - while recording bass

        # the next time the looper comes around, the song
        # machine will get the "loop" event and trigger
        # the following section of code ...

    loop:
        BUTTON_COLOR 1,red              # button to red
        DISPLAY 1,"VERSE1"              # what part of song are we in?
        DISPLAY 2,"recording bass1"     # what the heck are you supposed to be doing now!

    ... and so on

```

The above example lets you play an intro, then record a straight guitar part,
then play lead over it, then start recording bass over that, with only two button
presses.  The chosen synth patch, volumes and effects are determined by the code.
All you do is tell the machine **WHEN** to change state ...

More info on the songMachine and the songMachine language
can be found in the [songMachine readme file](songmachine.md).

## Note on Pedals and Display Areas

The handling of the expression pedals is *system-modal*.   That is to say,
the behavior of the pedals is not really bound to any given rig and the pedals
**continue to work** when you go to the configurationSystem and return to
a given rig (anywhere in the program).

This is because, in the real world, you may (probably) want to keep playing
the guitar while possibly changing configuration options, and certainly
at least want the ability to stomp on the pedals and turn everything down,
regardless of anything else that is happening, anywhere in the program.

So, although Rigs can affect the modal behavior of the pedals (set their
CC's and behaviors), the pedals themselves (pedals.h and cpp) actually send
out the pedal MIDI CC messages, and **there is no "Top Level Window" or
expSystem "onPedalEvent()" method**.

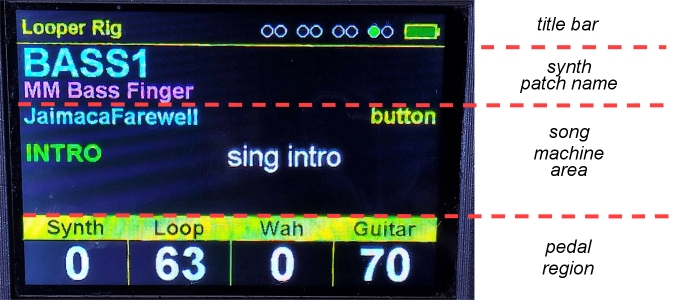
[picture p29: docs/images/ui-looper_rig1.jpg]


Also, here, it is worth noting that the TFT screen generally always presents
a **"title" bar**, which includes the context (rig name, configuration
option name, or modal dialog title) and the *midi activity* and *FTP battery level*
indicators.  Likewise, generally speaking, within Rigs **(all rigs) display the Pedal
Values portion** of the TFT screen, whereas the configSystem and dialogs
do not display them (though the pedals continue to work).

So the *"client area"* of the screen for a rig excludes the title bar and
pedal display area, and for all other windows, including the configuration system,
the client area excludes the title bar area.

These rectangles are publicly available in expSystem.h for general use.

## Final Notes

### *Patch* is a heavily overloaded term.

So I chose the term **"rig"** instead of **"patch"** to avoid confusion
with the things *THIS* teensyExpression pedal does (*rigs*) and *"patches"* that
might be selected on a synthesizer or other device in accordance with
their previously established terminology.

### I am not using the touch screen

Although the code exists to calibrate the touchscreen, and respond to touch events, in practice
I am merely using the TFT as a display device.

The whole point of a foot pedal is to not have to bend over and use your hands
to program it!

### This is not an end-user, consumer, ready device

As I have said before, my goal with this project was not to create an end-user ready,
consumer level, device.  My goal is to produce something that I can use and am
comfortable with.  So the device presents a very specific User Interface and set
of behaviors.

At this time, new "Rigs" are created by writing C++ code.

In a consumer level device, you would
probably be able to create, store, and modify "rigs" via the device itself.  But
it is easier for me to write C++ code, than to abstract all possible future potential
user interfaces out and make them user modifiable and persistant.

In other words, at this time, I am not willing to give up the potential flexibility
to make the device do what I want in the future (via C++) in favor of creating a
device that other non-programmers could use.

The best example of that is how the system currently knows
what midi CC messages to send out to communciate with the external (iPad based or
custom built) Synth, Guitar Effects, and Looper devices.  Those values,
the channels and CC numbers to send to communicate with those devices,
are hard coded into the C++.

Having said that I would like to make some points regarding this implementation.

- The device is interesting as it is, and this documentary effort can be
  instructive, have value, even if one does not actually go ahead and build
  an exact copy of this teensyExpression pedal.
- The UI and behaviors that have evolved for the teensyExpression *could* be
  used, as-is, to duplicate soething similar to my rig.  The CC numbers and
  channels are available by perusing the C++ code, and one *could* setup their
  iPad or other USB Midi based rig to accept and respond to those particular
  channels and CC numbers
- The whole idea of making this project public, and documenting it, is so that
  other capable makers can build it, and particularly that they can modify the
  C++ source code to make the pedal do whatever THEY want.  If someone wanted to,
  it would be a reasonable task to fork my code, and then implement their vision
  of a user-level consumer device ... even for resale ... if they wanted.

Some enterprising individual could take this code, and take advantage of the
touch screen capabilities, to expand the programmability of the device into
a consumer level end-user product.

I'm trying to accomplish a lot with this series of projects.  And I am very interested
in making it public, and available as completely free open source.  But my main
motivation is, and remains, to create a virtual guitar rig that I like, and that
I can use in live gigs.

### Creating a new Rig

Just derive a class from *expWindow* or *rigBase*.  In it's begin() method
set the buttons up how you want them by calling **theButtons.setButtonType()**.
Add an **onButtonEvent()** method that responds to the button presses
and does what you want (like sending out midi CC messages).

Or copy one of the existing rigs (rigLooper, rigTest, or rigDemo) cpp and h
files to another name, edit them to rename the objects, and go from there.

Then modify **expSystem.cpp** to instantiate the rig, and away you go!!

See the various API's (*buttons.h, myLeds.h, myTFT.h, etc*) for details on how
you affect the display and LEDs, and see **rigLooper** or one of the other
existing rigs for clues on how to send midi events upon button presses.

----- end of design/ui.md ------

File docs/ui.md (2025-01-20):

# Design (User Interface)

This page describes the software user interface, as currently implemented,
of the teensyExpression pedal.

For a discussion of the software architecture (how it works), please see
the main [Design](readme.md) readme file.

**--------------------------------------------------------------------------------**

## **the Looper Rig**

The Looper Rig (rigLooper.h and cpp) present the main user interface that I use while playing guitar.

There are four expression pedals plugged in, for, respectively,
the Synthesizer volume, Loop volume, Wah Wah (expression) pedal, and Guitar Volume.

The Looper Rig is the only code that makes use of the Rotary Controls at this time.
They are used to control the (bare metal rPi) Looper's INPUT, THRU, MIX, and OUTPUT volumes,
respectively.

### Screen

The Looper Rig screen shows several distinct regions.

At the top is the **title bar**, which includes the **title** of the current Rig, configuration option,
or dialog window, the **midi activity** indicators, and the **FTP battery level** indicator.

Below the title bar, the currently selected **Syntheizer Patch Short and Long names** are displayed
in large cyan, and smaller magenta, respectively.



Below that is the songMachine area, which shows:

- on the first line, in cyan, the **name** of the current song (JamaicaFarewell in this case)
- on the first line to the right, in yellow (or red if an error) the **"state"** of the songMachine
  (waiting for a button press in this case)
- on the second line, to the left, the **first user programmable display area**, by convention
  usually used to show one word describing WHERE you are in the song (i.e. INTRO, VERSE,
  CHORUS, END, etc) in yellow or green.
- the second line to the right (the rest of the screen down to the pedal region) is given
  to the **second user programmable display area**, which is also where any errors
  would be displayed, or more usefully, your user programmed message(s) describing, perhaps,
  what you should be doing (i.e. "Sing the Verse NOW!!!") or what is coming
  (i.e. "Get ready to record the bass!"), usually in white.

At the bottom of the screen is the **"pedal" region**, which shows, in yellow, the current values
for the Synth volume, Loop volume, Wah Wah value, and Guitar volume.

### Main Looper Rig Buttons

The Looper rig buttons are divided into 4 different groups.

The first group, occupying the top 3 rows of the left most 4 buttons, are the **Synth Patch selection
buttons**.  They pick one of twelve patches on the synth, within one of two "banks".  The **BANK/CONFIG**
button is the upper right most button.  Short clicking it will toggle between the two banks of
12 synth patches, and it's color will change from CYAN to BLUE to represent bank 1 and bank 2,
respectively. The patches that are selected also show the bank number they were selected under
by turning either CYAN or BLUE when pressed.

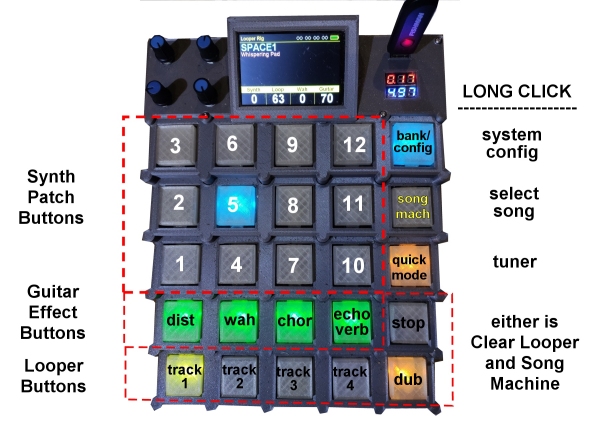
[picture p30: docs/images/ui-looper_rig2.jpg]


The second group of buttons, occupying the leftmost 4 buttons on the 4th row, are the
**guitar effect buttons**.   The buttons are, in order from left to right, *DISTORTION,
WAH, CHORUS,* and *ECHO/VERB* respectively.  Pressing them toggles the given effect on and off.
When the effect is on, the button is lit in green, when it is off, the button is not lit.

*Long pressing* the rightmost guitar effect button (the ECHO/VERB button) will clear
**(turn off) all the guitar effects**.

The entire bottom row of buttons, plus the one above the right corner, are the **Looper
buttons**. They are, from left to right, the *TRACK1* through *TRACK4* buttons, the *DUB* button,
and above the DUB button, the *STOP* button.  *Long pressing either* the DUB or STOP button
will **clear the Looper** (and, if a song is loaded in the songMachine, it will clear the
songMachine too).

Finally there is the right most column of buttons, which from the top down, are,
respectively, the ***BANK/CONFIG button***, the ***SONG_MACHINE button***, the
**QUICK_MODE/TUNER button**, and as previously mentioned, the Looper STOP and DUB buttons.

*Long pressing* the upper right BANK_SELECT button **takes you to System Configuration mode**
(rig #0) as described later in this document, whereas a normal click merely toggles the selected
bank (color).

### Song Machine Button (loading songs)

*Long pressing* the ***SONG_MACHINE*** button brings up the *Select Song dialog*, which lets you
load a song into the song machine.  It uses the usual blue button arrow pattern seen
elsewhere in the system:

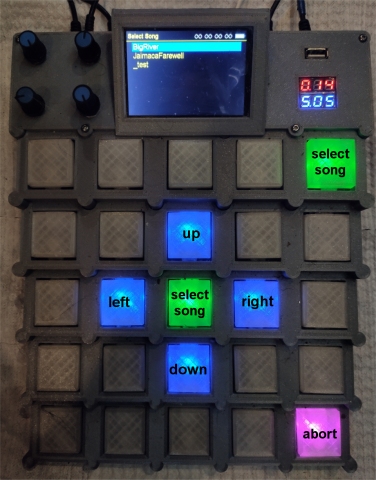
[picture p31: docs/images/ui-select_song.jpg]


While in the Select Song dialog, the blue ***UP*** and ***DOWN*** buttons move between songs,
whereas the ***LEFT*** and ***RIGHT*** buttons show you the contents of the
text file, or move back to the list.  Within this dialog, the green buttons mean ***SELECT
SONG***, which will cause it to be loaded and started running, and the magenta button
means ***ABORT*** without loading a song.



When a song is loaded, the songMachine button changes to yellow, and a *short click* of the
SONG_MACHINE button toggles the songMachine between *"running"* (yellow) and *"paused"* (purple)
states.

When a song is loaded, and the songMachine is running, **it takes over the bottom left four (track) buttons**.
When it is not running, or no file is loaded, those four buttons revert back to the the normal Looper
TRACK1 through TRACK4 buttons.

Please see the [songMachine readme file](songmachine.md) for more information about
the songMachine.

**There is a small, kind of weird, overload of the songMachine button.**

*When a song is not loaded, a short click on the (blank) SONG_MACHINE button will set a
**LOOPER_MARK_POINT** in the current loop if any is playing.  If that happens, instead
of looping back to the beginning of the clips, the rPi Looper will start looping back to
the marked point, allowing you do things like "repeat the last phrase 3 times then end"*.

*This functionality was stuck here in lieu of a (quite likely) rework of the UI to
allow another row of looper control buttons (at the expense of one row of synth
patch buttons, recovered by increasing the number of synth banks from 2 to 3 or more).*

### Quick Mode Button (and Guitar Tuner)

I call it "Quick Mode" but you could also call it "Looper Mode".

A short click of the QUICK_MODE button will toggle between "normal Looper Rig Mode" and a mode
that takes over the synth patch select and guitar effect button areas and re-programs them to
allow you to MUTE/UNMUTE and adjust the volume of each the four clips (layers) within the currently
running Track on the Looper, if any.



The MUTE/UNMUTE buttons are blue if the clip is NOT muted, and they change to magenta if
the clip IS muted.  Above the MUTE/UNMUTE buttons are the VOLUME_DOWN (orange), and VOLUME_UP (green)
buttons.  Pressing these will adjust the volume of the given clip within the current track.

Finally the top row in Quick Mode is given over to track managment.   There are four
buttons that turn red if a track has been recorded.  If so, long pressing the button
will erase the track (and stop the looper if that track happens to be playing).
This allows you to re-use tracks for more complicated songs, or just get rid
of problems without necessarily throwing the whole set of clips away.

One of the buttons in this top row may be orange if that track happens to be
currently recording.  If so, a short click of the orange button will abort the
reording (and keep looping, if possible).  That is the "oops, messed up, bail"
button while recording.

A second short click of the QUICK MODE button will return you to "Normal Looper Rig"
mode, where once again, the synth patch and guitar effect buttons are in effect
and displayed.

*A long click of the QUICK_MODE button will bring up the FTP guitar tuner (described separately)*

**--------------------------------------------------------------------------------**

## **System Configuration** mode (rig #0)

The second main user interface in the system at this time is the *configuration/preferences*
code, which is called the **configSystem** (h and cpp files, respectively).

You enter **configuration mode** by *long clicking* on the upper right hand button
in any rig.   In the Looper Rig, that is the BANK/CONFIG button.  When in configuration
mode, the upper right hand button turns to magenta.

You exit configuration mode by pressing the upper right hand button.  A *short
click will* accept the modifications you made to the system configuration
**for this session only**, whereas exiting with a *long click* will save the
changes persistently to EEPROM so that they define the default state of
the device when it reboots.

So, for example, you can change the LED brightness, and if it's just for
temporary use, a short click exit will keep the change, but rebooting
will use the persistent preference.   A long click will set the LED
brightness (default) for the next time you reboot the machine.



The configSystem presents a general **up-down-left-right-select** pattern
of buttons, along with a few "special" (short cut or exit) buttons.

In general, you move the cursor up and down to to navigate to a
configuration option, then press the **select** button to modify
the value (or go deeper into the configuration hiearchy).  The
detailed configuration options will be discussed below.

The right arrow also typically means *go deeper into the configuration*.

The left arrow generally means *return to the previous page*, moving
back to the main configuation page.

In addition to the arrow-select keypad, there are a number of other
buttons for quicker access to certain parameters, or to reboot the
machine.

- the **top left red and green buttons** increase or decrease
  the LED brightness
- the **second row of buttons** lets you pick between rigs
  1 through 5, and shows the currently selected rig if it
  is in that range. In the above image, rig #1, the Looper
  rig is selected.
- the orange button second from the top right is the
  *abort* button.  Short clicking it will abort any
  changes you have made to the configuration and
  return you to the current rig (as opposed to
  clicking the top right button which **accepts**
  the changes).
- *long clicking the orange button* will **reboot the machine**.

### Configuration Menu Hierarchy

Details about certain settings will be provided below.

```
    1. Brightness                   NN      # sets the LED brighntess
    2. Rig                        name      # chooses different rigs
    3. FTP                         ...      # brings up the FTP submenu
    |  1. Spoof FTP             off/on      # turn FTP spoof mode on or off
    |  2. FTP Port     off/host/remote      # where is the FTP dongle?
    |  3. FTP Tuner                ...      # brings up the FTP tuner dialog
    |  4. FTP Sens                 ...      # brings up the FTP sensitivity dialog
    4. Pedals                      ...
    |  1. Configure Pedal1 (SYNTH)          # brings up the pedal configuration
    |  2. Configure Pedal2 (LOOP)           # dialog for one of the four expression
    |  3. Configure Pedal3 (WAH)            # pedals ...
    |  4. Configure Pedal4 (GUITAR)
    5. Midi Monitor                ...      # Midi Monitor Settings
    |  1. Midi Monitor      off/default/usb/serial      # where to send midi monitor output
    |  2. Ports                    ....
    |     1. Duino Input 0       off/on     # there are eight midi ports that can be monitored
    |     2. Duino Input 1       off/on     # each midi device has two ports
    |     3. Duino Output 0      off/on     # the "duino" ports are the main teensyDuino USB device
    |     4. Duino Output 1      off/on
    |     5. Host Input 0        off/on     # the "host" ports are the teensy 3.6 USB host device
    |     6. Host Input 1        off/on
    |     7. Host Output 0       off/on
    |     8. Host Output 1       off/on
    |  3. Channels                  ...     # you can filter midi monitoring by channel
    |     1. Channel 1           off/on
    |     ....
    |     16. Channel 16         off/on
    |  4. Message Types             ...     # you can filter midi monitoring by message type
    |     1. FTP Specific           ...     # there are a number of options for FTP specific messages
    |        1. ParsePatches     off/on     # Parse FTP patches into meaningful display? (requires sysex)
    |        2. Note Info        off/on     # Monitior FTP Note Info messaage
    |        3. Tuning Msgs      off/on     # Monitior FTP Tuning messaage
    |        4. Commands         off/on     # Monitor FTP commands
    |        5. Values           off/on     # Monitor FTP command replies
    |        6. Poly Mode        off/on     # Monitor specific FTP command/reply: PolyMode
    |        7. Bend Mode        off/on     # Monitor specific FTP command/reply: Bend Mode
    |        8. Volume           off/on     # Monitor specific FTP command/reply: Volume Level
    |        9. Battery          off/on     # Monitor specific FTP command/reply: Battery Level
    |       10. Sensitivity      off/on     # Monitor specific FTP command/reply: String Sensitivity
    |       11. Known Commands   off/on     # Monitor any other specific known FTP commands/replies
    |       12. Unknown Commands off/on     # Monitor umknown 1f/3f FTP commands/replies
    |     2. Sysex         ff/on/detail     # Monitor sysex messages, details=show contents
    |     3. Active Sense        off/on     # Monitor active sensing messages
    |     4. Note On             off/on     # Monitor Note On messages
    |     5. Note Off            off/on     # Monitor Note Off messages
    |     6. Velocity            off/on     # Monitor Velocity messages
    |     7. Program Chg         off/on     # Monitor Program Change messages
    |     8. Aftertouch          off/on     # Monitor Aftertouch messages
    |     9. Pitch Bend          off/on     # Monitor PitchBend messages
    |    10. Other CCs           off/on     # Monitor Any other CC's
    |    11. Everything Else     off/on     # Monitor Everying else
    6. Perf Filter                  ...     # Performance Filter settings
    |  1. Perf Filter            off/on     # Turn performance filter on or off
    |  2. Filter Bends           off/on     # Filter out pitch bend messages
    |  3. Monitor Perf           off/on     # Monitor the peformance MIDI messages
    7. System                       ...     # Change system wide settings (ports, etc)
    |  1. Debug Port     off/usb/serial     # Where to send program debugging output
    |  2. File Sys Port      usb/serial     # Which serial port to monitor for fileSystem comamnds
    |  3. Calibrate Touch           ...     # Calibrate Touch Screen (not implented yet)
    8. Factory Reset                ...     # Perform a factory reset (with confirmation dialog)
```

#### - Options Requiring Rebooting

Changing some options requires rebooting the machine.
If you change the following options you *should* be prompted with a
yes/no confirmation dialog, and if you **save** the options,
the machine will reboot.

- Factory Reset
- FTP Spoof Mode
- System Debug Port
- fileSystem Port

The machine can also be rebooted by long-pressing the orange **abort** button.

When the system reboots, the button will flash red for a few second before
actually rebooting.

#### - Factory Reset (default settings)

Performing a factory reset clears the EEPROM memory (writes 255's to it all).
This results in the default settings being used upon the reboot.

The default settings are to turn Midi Monitoring off, expect an FTP
dongle on the remote (main usb to the iPad) port, use Rig #1 (the
Looper Rig), and communicate with the (bare metal rPi) Looper via
serial midi.

#### - FTP Spoofing (explained)

When FTP spoofing is turned **off**, this device presents itself
as a compliant USB midi device with four ports

- teensyExpression IN 0
- teensyExpression IN 1
- teensyExpression OUT 0
- teensyExpression OUT 1

When FTP spoofing is turned **on** this device presents itself
**as an FTP USB device** with a different set of four ports:

- Fishman Triple Play - (in 0)
- Fishman Triple Play - (out 0)
- MIDIIN2 (Fishman Trple Play) - (in 1)
- MIDIOUT2 (Fishman Trple Play) - (out 1)

**IF you plug an FTP dongle into the USB Host port** and engage
*FTP spoof mode*, you may then plug this teensyExpression pedal into
your Windows machine, and can **run the Fishman FTP Windows**
application, and it will *see* the teensyExpression **AS**
a Fishman FTP device!!

You can then use the *Midi Monitoring* capabilities,
in conjunction with Putty or some other serial port
monitor, to *monitor and understand the conversation*
between the FTP dongle and the FTP editor program.

This functionality, alone, should be of value to any hard core
hackers that are trying to reverse engineer the FTP dongle.

Note that I belive that one *could* build the INO program **without necessarily
building the box**, run this program on a bare teensy 3.6,
and take advantage of, and use, these monitor features ...
with a little work ... by setting the defaults at bootup
to turn on the FTP spoofing.

**I would be very interested to hear if anyone can build
this source code!!**

#### - FTP Host Port and MidiFire on iPad

If the FTP port is set to **host** and you plug an FTP dongle
into the host port, it will work.

But, to use the FTP in **remote** mode, in my setup, I need
to run a program like **midiFire** on the iPad and *redirect
the FTP output* (for Channel 8, on which the FTP sends out
all of it's command/reply messages) **BACK to the teensyExpression**
input midi device.

The FTP Port must be setup correctly to use the ftpTuner
and ftpSensitivity dialogs, and/or to monitor the FTP
midi messages.

#### - System Debug Port and Midi Monitor Port

Debugging output from the program can be turned off, or
directed to either the main USB serial port, or the ancillary
serial port (the 1/8" jack on the back of the box).

The Midi Monitor output can "follow" the debugging output.
If it's port is set to "debug", it will use the setting
of the System Debug port for it's output.

Or the Midi Monitor can be specifically directed to
either the main USB or the ancillary serial port.

So, it is possible, if you desire, to (perhaps using
an rs232 USB Serial Dongle) to connect the Midi Monitor
to one console (instance of "putty") on your development
machine, and have the debugging output from the program
go to a separate different instance.

So you could have two serial "consoles" open to the
teensyExpression pedal at any given time.   This is
handy sometimes when you are debugging, but still
want to monitor the midi messages.

#### - Midi Monitoring, General and FTP specific

You can generally turn Midi Monitoring on or off, as well
as filtering on specific *ports* and/or *midi channels*.

In addition, you can choose to filter out (or show) specific
midi messages, like, for example, **sysex** which can be
shown as a single line, that just tells you how many bytes
of sysex were in the message, or it can include a dump of the actual
sysex bytes in the monitor.

If you are monitoring a Fishman FTP Triple Play Dongle,
you can also choose to further parse FTP sepecific messages,
including to display the contents of FTP patches in a
meaningfule manner as they are being slung back and forth,
and/or to interpret the
FTP **1f/3f** *command/reply* sequences.

For more information on my efforts at reverse engineering
the FTP Midi protocols, please see the
[ftp readme](ftp.md) file

TODO: Make a readme file specific to Midi monitoring
showing how it displays messages in differet colors
depending on the ports and message types, and demonstrating
how it can help to understand complicated MIDI conversations.

### **Pedal Configuration Dialog**

The **Pedal Configuration** dialog is available for each
of the four expression pedals.   As with the main system
configuration dialog, it presents a **blue button arrow/select
button pad**.

Within this dialog, you use the **up** and **down** buttons
to navigate to an item, for example, the *curve type* for the
pedal, and then use the **select** button to change the value.



The available curve types are

- **linear** - (a simple line) has only *max* and *min* points to edit
- **asympt** - (asymptotic) has *max* and *min* and one point, *mid* in the middle
- **scurve** - has *max*, *min*, and two adjustable points (*left* and *right*) in the middle

When you select one of the **points** for editing the curve,
all four arrows, *up*, *down*, *left*, and *right* may be used
to move the selected point around on the curve.  A subsequent
press of the **select** button then returns to allow you
navigate the pedal configuration options.

When you select the **calibrate** option, you should move the
pedal back and forth to it's minimum and maximum settings a few
times, and the program will use those values in subsequent
calculations.

You can press the top right **green** button to save your
pedal configuration changes, or the **orange** button to
abort them.

You can change to the next pedal (and accept the changes
to the current pedal) by pressing the **purple** button
on the upper left.

If you have made changes to a pedal configuration, and
left this dialog window with the *green* *accept* button you
can then save those changes persistently, if you wish,
when exiting configuration mode by *long pressing* the
**exit configuration mode** button.

#### - Special Behavior for Loop Pedal set to Serial.

The pedal type can be set to **Normal** or **Serial**.

The **normal** setting will send out typical MIDI CC
messages (as determined in pedals.cpp) for the various
pedals.

In the **normal** setting, the *Looper Rig* **LOOP pedal**
and buttons are setup to work with a looper program running
on the iPad with (my certain) known CC numbers.

However, if the **LOOP pedal** type is changed to **serial**, then
the Looper rig expects to control and communicate with my
**[bare metal rPi Looper](https://github.com/phorton1/circle-prh-apps-Looper)**
via serial commands out the 1/8" jack on the back of the box.

**--------------------------------------------------------------------------------**

## **FTP Guitar Tuner and Sensitivity Dialogs**

The **FTP Tuner** only has one active button, the **green** button
to return to the configuration mode (or rig) although it
*displays* the tunning state on a series of three buttons
in the middle of the button array.



The FTP Tuner also displays a **guitar fretboard** showing the individual
notes being played on each string, which I think is kind of cool!

The FTP Sensitivity dialog has a typical **blue button arrow/select**
set of buttons where *up* and *down* allow you to select the string
you wish to adjust (and/or the *Touch Sensitivity*, *Dynamic Range*,
and *Dynamic Offset* of the FTP pickup).  The *left* and *right*
buttons, respectively, decrease or increase the given value.



The **VU meters** show the relative MIDI Note On velocity values for each
string  The FTP delivers these in a comprssed format with a non-linear
dynamic range. The **white line** shows the relative, uncompressed
MIDI Note On velocity.

The **green** button at the *lower right* accepts the changes and
returns to configuration mode or the current rig.

#### - Toggling between Tuner and Sensitivity Dialogs

When you access the FTP Guitar Tuner from the Looper Rig (by long pressing
the QUICK_MODE button), once in the Tuner, you can toggle between the
Tuner and the Sensitivity dialogs by pressing the **purple** button
at the upper right.

----- end of ui.md ------

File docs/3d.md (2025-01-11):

### teensyExpression Fusion, STL, and gcode files

## Hours/Grams to Print

- Display Case	1:58	36.34
- Display Ins	1:34	30.47
- PCB Base		1:09	20.66
- Fastners		0:25	4.61

- Frame5 		7:33	150.35
- Frame4		5:49	117.26
- Frame3		4:45	93.88
- Frame2		3:31	69.95
- Frame1		3:13	65.23
- Top1			2:30	48.97
- TopMiddle x3	2:35	49.17
- Top5			2:49	53.66
- TopLeft		1:41	32.42
- TopRight		2:02	38.82
- Back			2:34	53.05

The file 2020-06-02-MidiPedalFinal_with_fixes v9.f3d contains the most recent, and
most correct, version of the design of this thing.



But I don't believe it contains the actual switches themselves, which were
probably last exported from 2020-05-19-MidiPedal2 v4.f3d



THIS IS THE INITIAL CHECK IN.

I will clean these up and provide a single fusion file, and set of STL
and Prusa specific m3f and gcode files by the time I post this to
thingeeverse.

For now I just wanted to get a version up on the web.

ALL OF THIS IS USER BEWARE, of course!

Use at your own risk!

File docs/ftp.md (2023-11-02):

# FTP (Fishman Triple Play) Reverse Engineering and Midi Specificiations

TODO: many broken links in this file

The folder contains historical and more up-to-date results of the last couple
of years of my efforts to reverse engineer the FTP midi specification and behavior.

Some information about those efforts is not present in this directory, but rather
in C++ header and source files in the /arduino project itself, but this page *should*
serve as an entry point to the overall notion of those reverse engineering efforts.



Above is a modal dialog window on my device that lets me adjust the string
sensitivity of the FTP dongle/controller.

## A short History and a Rant

I purchased my first FTP in November 2018.   I programmed my first Arduino in
January of 2019.   These were not unrelated incidents.

How I long for the engineering ethics of the 1980's, when you would buy a device,
say a Yamaha FB04 or Kawaii Synthesizer, or maybe a TR-505 drum machine, and included
in the documentation would be a more or less complete specification of how the device
interacted with MIDI, including detailed specs about midi syses messages.

Those days are long gone.

Nowadays when you buy a device, most likely you will not be able to find out anything
about it's midi sysex implementation, although it has one.  For example, there is
an Akai drum-pad that is ubiquitously available, the MPD218.   It comes with a "patch
editor" for Windows (and probably the Mac), that is *adequate* for a consumer to
edit the configuration so that it does what is expected, i.e. when you press a pad,
you can program it to send a MIDI note on-off, or CC message on a given channel.

But nowhere can you find the necessary information to **write** a patch editor for it.

It is a relatively simple device, and I have reverse engineered most of it's sysex, a
topic for another project and discussion, but it rankles me that these manufacturers
have moved away from detailed public MIDI specifications and force the public to rely
solely on platform specific implementations of their choosing (i.e. the MPD218 window
editor).   While that program is adequate, it is also "lame" ... it creates mulitple
instances of the application to deal with each "preset" you are editing, has a convoluted
way of getting around.  For instance, to merely edit one parameter on the device, you
boot one instance of the program "download" the patch from the device, which instantiates
ANOTHER instance of the program, modify the parameter, "upload" the changed patch
through a somewhat complicated relationship with the storage locations on the device,
and then, after that (so you have changed ONE number on the device), you then have to quit
two programs, answering "no" to "do you want to save your changes" messages for each
program ... even though in the first instance you didn't change ANYTHING.

Anyways, I think these manufacturers are missing the point, and a big opportunity, by
NOT publishing their specifications.

And nowhere have I found this to be more true than with the Fishman FTP Triple Play
device and it's midi-implementation and behavior.

Physically, it is a beautiful implementation.   A hardware piece-de-resistance.
Functionally it boasts perhaps the best guitar-to-midi convertor on the planet,
at least from what I've read and been able to surmise, with the best response times,
most accurate tracking, and wonderful features like adjustable string sensitivity.

Yet, as you can read on many forums, and many owners know, it is a complete black
box. It's behavior is exceedingly complicated, as well as undocumented. You are forced
to use Fishman supplied software to do anything useful with it.  Otherwise, if you
don't want to use the Fishman software, you are supposed to think of it as a "generic
compliant USB midi device", though there are "magic" buttons that can be pressed,
and settings in the editor which can (and do) affect its behavior as such.

The whole thing has been very frustrating for me.

I now own two of the devices, as one of the pickups went bad on one of the devices.

I use the device in live gigs, and NEEDED to have a working unit.

----------------------------------------------------------------------------------

It took me about a month to realize that, apart from the crucially necessary
windows version of the FTP configuration editor, I had no use for the literal
mountains of other software FTP provides (foists?) upon their end users.

This was before the iPad specific version of their software, which is nice,
but which also completely misses the mark due to it's lack of external midi
controllability.

I think a large part of it derives from marketting and sales driven forces at Fishman.

In my opinion, Fishman *should have* released the hardware with a detailed description
of the MIDI implementation, and left the software, more or less, up to others to create.
*Maybe* the patch editor would be necessary.

But in today's world of "plugins" and cooperative marketing agreeements, software
bundling agreements, and so on, you get a device that tries to do EVERYTHING,
interface with every kind of software on every platform, but yet, which is
basicially impossible to understand or use separate from THEIR pre-conceived
notion of what software their end users WANT ... and **NEED** ... to use.

So, that's the end of my rant (for now).   Fishman missed the mark totally on the
software/firmware side of their device.   Where they sell 10,000 units now, they
could be selling 100,000 units.   Where they have to create complicated agreements
with software vendors and relationships that they force upon their user, they *should*
have made the internals specifications more public, and taken advantage, rather than
squashing, the larger community of open source and hacker type programmers.

Nonetheless, I have put considerable effort into figuring this damned thing out,
and this repository contains most of those results, though perhaps not in the
most ordered, or organized, presentation.

# Documents in this folders

As this is my initial commit of these materials, I am starting by merely posting that
which I already have, in whatever state it happens to be in.   Below I try to give
an idea of the relevance of each document in this folder.

### \[my_devices_midi_descriptors.txt](my_devices_midi_descriptors.txt)

This file contains a dump of the the USB descriptors for various devices that I have owned,
including the FTP, the Akai MPD218, a Softstep2 foot pedal, an "AudioFront" exprssion pedal
to USB midi convertor box, an Akai MPK mini keyboard, and a Behringer UMC4040HD Audio USB
interface.

I created this file in my "early days" with Arduinos and the Ardunio USB Host Shield,
and have referred back to it many, many times, as I have tried, and ultimately suceeeded
in "spoofing" the FTP editor so that I could intercept and learn about the MIDI implementation
of the FTP device.

Others who might *not* be interested in the FTP may still find interest in the descriptors
for one of the other devices therein.

### \[FTP_Midi_Analysis.docx](FTP_Midi_Analysis.docx)

This file was also generated using Arduinos (or maybe a teensy) and various Arduino host shield
solutions.  I got quite involved trying to implement an (unpublished) "USB Pass Thru" device that
would allow me to generally spoof any USB (midi) device.  Maybe I'll post that someday.

So, this document has exmples of my earliest efforts to get at the FTP patches via sysex, which
I initially "sort of" got working at an ad-hoc level.  I also got very close (but no cigar)
to understanding how to adjust the FTP string sensitivity and other things, like polymode,
at that point.

I even put some stuff up on the vGutiar forum at that point, including a basic C++ data
structure for the patches on the FTP.   Unfortunately, by the time I got back to the project,
my notes were scattered, and I had to, basically, go through everything again.

But I did.   If you've read this far, keep reading.

### \[readme-2020-06-14.txt](readme-2020-06-14.txt)

Of course, one of the things I initially tried right away with the FTP was to use the
**midiOx** program to *get in between* the windows FTP editor and the dongle/controller
so that I could see and learn about the midi messages flying back and forth between the
two.   It is fairly easy to see one side of the conversation (the output FROM the dongle
TO the editor) as the FTP has two "output" ports, and only one of them is really needed
to run the editor.

But it proved difficult (for me) to visualize and get at the TWO-WAY communication that
was taking place.

So, finally, about a month and a half ago (I'm writing this on July 31, 2020) I finally got really
down into it and figured out how to spoof the FTP editor using **loopMidi** and **midiOx**.

This document is/was a "realtime" experimental log, including things that *didn't* work.

At the end of it, I started another MSWORD document (next) so that I could include
pictures and desribe the results mo-better.

### \[FinallyFiguredOutMidiOXSpoof.docx](FinallyFiguredOutMidiOXSpoof.docx)

This document purports to explain how YOU TOO (lol) can use **midiOx** and **loopMidi**
to get *in between* the FTP dongle and the Windows FTP editor program so that you can
see the conversation taking place between them.

Somewhere around that magic moment, the flood gates opened and I started getting a
much better idea of how they editor and dongle/controller communicate.

Those efforts have now led to **more information than I can document** sigh/lol.

I ask the interested reader to continue reading.   Most of the really *juicy* stuff
is in C++ header and source files at this time, which I will attempt to link to in the next
major section of this readme file.

### \[hardware_patches.csv](hardware_patches.csv)

A CSV (comma delimtied text) file of the original FTP hardware patches created by using the
"export" function from the FTP Windows Editor.

This file was very useful in doing parametric analysis of the patches, so that i could see
WHAT changed when I changed soemthing in the patch editor, without necessarily needing to
see the midi-stream.

It also alludes to some as-yet-unimplemented or previously-implemented-but-now-vestigal
features that Fishman either had in mind and did not implemnt, or have yet to implement
(like an arpegiator).

### \[FTP_MIDI_SPEC.xlsm](FTP_MIDI_SPEC.xlsm)

This file is just getting started.   It was my intention to document here, in one place
all of the 0x1F/0x3F commands that the editor uses, and the dongle/controller responds
to.

That sentence will take a little explaining.

But, before I get around to tyring to advance the state of the documentation I have,
as I said, I want to do an initial commit, and get some of this info up on the net,
so for now, please just consider this as an as-yet unfilled framework for presenting
FTP commands and responses.

More later ....

# FTP information in teensyExpression source and header files

As I said, most of the information I have currently accumulated is currently lodged
in various C++ header and source files in the main "teensyExpression" project.

I try to call out the most relevant files containing FTP midi information here.

### \[../arduino/teensyExpression/ftp_defs.h](../arduino/teensyExpression/ftp_defs.h)

**This is probably the most important and relevant file for FTP midi
information, in my system, at this time!!**

This file contains the basic C++ data structures for a patch, as well as comments
and constants describing a variety of what I call 1F/3F command and reply
messages that I have ferreted out.

Basically it amounts to the editor sending out PAIRS of midi command messages
and the dongle/control replying with it's own pair

```
   0xBn   0x1F  command              sent by editor
   0xBn   0x3F  param                to controller
```

The editor sends (continuous controller) messages on channel "n+1".

So 0xB1, for example is a message sent out on Midi channel 2.

Command and control of the dongle/controller takes place on Midi Channel 8, so the 'n' in this case is '7'.

Each "command" is typically paird with a "parameter" that the editor can send.

For instance, the command might be "set string sensitivity" and the parameter
might be a bitwise combination of the string number (0..5), and the sensitivity
level (0..15).

After receiving the command, the dongle typically "replies" with the same
command header, but perhaps some other information in the "parameter".

```
   0xB7  0x1F  command              sent by controller
   0xB7  0x3f  reply-value          to the editor
```

--------------------------------

In this H file you will find most of the command/replies that I have identified,
and/or tested, and/or which I use to effect things in the teensyExpression program.

For instance, I was able to implement the "string sensitivity settings"
in \[winFTPSensitivity.h](../arduino/teensyExpression/winFTPSensitivity.h) and
\[winFTPSensitivity.cpp](../arduino/teensyExpression/winFTPSensitivity.cpp)
as well as a guitar tuner based on the FTP, largely based on the information
available in this H file.



also see \[winFTPTuner.h](../arduino/teensyExpression/winFTPTuner.h) and
\[winFTPTuner.cpp](../arduino/teensyExpression/winFTPTuner.cpp)

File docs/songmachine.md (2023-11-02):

# The songMachine

This page describes the **songMachine** and the **Song Language**.

## songMachine

The songMachine *"runs"* programs written in the **Song Language**.  The song language
is case insenstive, and can have line oriented comments in them,
delimited by pound signs **(#)** as in perl or bash scripts.

Please see the **songs** folder for some examples of **.song** files.

The songMachine allows you to automate complicated series of button presses
and behaviors so that you can typically orchestrate a live looped
song with 3 or 4 button presses.

The songMachine gives you **four user programmable buttons**
(the bottom left four buttons on the teensyExpression), and
**two user programmable display areas** on the TFT display.

It abstracts the behavior of the teensyExpression and associated
Looper into a series of **statements** that can (and will) be exectuted
in a deterministic order.

It includes **flow control** constructs, like **GOTO** and **METHOD CALLS**,
and allows you to trigger behaviors based on **button presses** or **loop points**.

### - Flow of Control - blocking and button and loop labels

Execution of the program starts at the beginning of the file and
proceeds until a **loop:** label or **button1-4** label is encountered.

If the machine is pending a *loop* label, the next time the Looper
comes around to a **loop point** that section of code will begin
executing.

If you press one of the four **buttons**, the machine will look
forward until it finds a label for the given button, and will
execute that section of code.

A *button* may *jump over* a loop label, but a loop
event **cannot** jump over a button label.

**METHODS** are treated as separate sub-programs with their
own scope for buttons and loop labels.  A button press
outside of a method **will not** jump *INTO* the method.

*It is beyond the scope of this document, at this time, to
go into excruciating detail about the songMachine behavior.
Hopefully there will be some **videos** forthcoming that
will make it clearer.*

**---------------------------------------------------------------------**

## Song Language (.song files)

### - CONSTANTS

The song language supports the following **constants** as parameters to certain statements

**Colors** apply to either the text in the TFT shown by the DISPLAY sttement, or the
color of buttons in the BUTTON_COLOR statement.

- **RED**
- **GREEN**
- **BLUE**
- **YELLOW**
- **PURPLE**    - this is actually magenta in practice
- **ORANGE**
- **WHITE**
- **CYAN**
- **BLACK**

**Buttons** may optionally be told to *"flash** in the BUTTON_COLOR statement

- **FLASH**

**Looper Clips** may be *muted* or *unmuted* in the LOOPER_CLIP statement

- **MUTE**
- **UNMUTE**

**Guitar Effects** can be turned *ON* or *OFF*

- **ON**
- **OFF**

**Numbers:**

- **Numbers** are generally integers, and limited to 3 digits.
- **Volumes** are numbers in the range of 0 to 127
- **Delays** are measured in 10ths of a second from 0..255,
  allowing for delays of 0 to 25.5 seconds to be stored in a single byte.
- **button numbers**, **track numbers**, and **clip numbers** are limited to 1 through 4

**Identifiers** and **labels**

All of the words in the langauage are reserved.  The button
and loop labels are followe immeidately by *colons*.

Anything else is a potential user defined identifier.
Identifiers must start with A-Z, or a-z, and may include numbers,
dashes, underscores, and dots in them.

### - Statements

The song language supports the following **statements**L

**Display Statements**

- **BUTTON_COLOR** *button_num,color\[,opt_flash]* - set the given button
  to the given color.  May optionally include (comma) **FLASH** to make
  the button flash.
- **DISPLAY** *area_num,"quoted string"\[,opt_color]* - The DISPLAY statement
  shows text on the TFT in one of the two display areas (1 or 2).  You
  must provide a quoted string for the text to display, and the statement
  takes an optional **color constant**.   The default color for area
  number 1 is green, and the default color for area 2 is white.

**Volume Statments**

- **LOOP_VOLUME** *value\[,opt_fade_time]*
- **SYNTH_VOLUME** *value\[,opt_fade_time]*
- **GUITAR_VOLUME** *value\[,opt_fade_time]*

  The LOOP, SYNTH, and GUITAR
  VOLUME statements allow you to set the volumes (pedals) to the given
  values. These statement accept an optional **fade time** parameter,
  measured in 10ths of a second over which the given volume change will
  take place. A fade_time of zero (0) means that that the volume change will take
  place immediately.  The default fade time, if none is specified is
  2 (0.2 seconds) to avoid pops and clicks from abpruptly changing
  levels.

**Synth Patch Statement**

- **SYNTH_PATCH** *identifier* - the identifier must be the **short name** of one of the
  currently available patches (on any bank).  These names are currently hard-coded in
  rigNew.cpp

**Guitar Effect Statements**

- **GUITAR_EFFECT_NONE** - turns off all guitar effects
- **GUITAR_EFFECT_DISTORT** *on/off*
- **GUITAR_EFFECT_WAH** *on/off*
- **GUITAR_EFFECT_CHORUS** *on/off*
- **GUITAR_EFFECT_ECHO** *on/off*

  The guitar effects may be turned *ON* or *OFF*

**Looper Statements**

- **CLEAR_LOOPER** - clears the Looper returning it to an empty state ready to record a new song.
- **LOOPER_STOP** - stop the Looper normally at the next *loop point*
- **LOOPER_STOP_IMMEDIATE** - stop the Looper immediately
- **LOOPER_TRACK** *track_number* - is the functional equivalant of pressing one of the
  four **Track1-4** buttons.  The behavior of the Looper in response to a Track Button press
  depends on it's running state and the state of the *DUB* button.
  For example, on an empty looper, the first press begins *recording* a song, and the
  second press starts *playing it*.
- **LOOPER_CLIP** *clip_num,MUTE/UNMUTE* - mute, or unmute, the given clip (layer)
  within the **currently selected** track.
- **DUB_MODE** - the DUB mode (in the rPi looper) is a one-shot mode that applies
  to the *next* Track button that is pressed.  In the cannonical example, from an
  empty looper, pressing Track1 once will start recording the first clip on track1, and pressing
  it again will begin playing that clip.   *But what if you wanted to immediately record the
  second clip?*  You would **first** press the *DUB_MODE* button (execute the DUB_MODE statement)
  and **THEN** upon the second Track1 button press, the Looper will not only start playing the
  1st clip, but will start recording a second clip (layer) within the track.
  The *DUB_MODE* button works between tracks
  too, so that you can, for example, switch to a different track and both start playing it **AND**
  recording another clip in it, on the next track (subject to loop point considerations)
  as opposed to merely playing it.
- **LOOP_IMMEDIATE** - loop all clips in the current track, immediately, back to their starts
  (or the last **MARK POINT** if one has been set)
- **LOOPER_SET_START_MARK** - notify the looper to set a **MARK_POINT** which it will
  subsequently loop back to, within the currently playing Track, if any.  This allows
  you to do things like *"repeat the end of that phrase three times"* from **within**
  a given track.  Track MARK_POINTS are cleared when the current or selected track
  is changed.

**Control Flow Statements**

- **DELAY** *tenths_of_a_second* - will introduce a delay in the songMachine.
  This is useful, for instance if you want to fade the guitar down, and **THEN**
  fade the synthesizer up.   Otherwise, the fades would happen simultaneously.
  *DELAY* can also be useful after recording a track before changing volume levels
  to allow for the *inter-clip crossfades* in the (rPi based loopoer) which, by
  default, have a crossfade time of about 30ms.
- **GOTO** *identifier* - will jump to a user defined label (an identifier by
  itself followed immediately by a colon).
- **CALL** *identifier* - will call a defined method
- **METHOD** *identifer* - defines a section of code as a *METHOD* with it's own
   button and loop scope.  Methods may NOT be nested.
- **END_METHOD** required at the end of any methods.

Note that an identifer by itself, followed by a colon is a statement (a label) for use
with the **GOTO** statement, and that the special labels **loop:*, **button1:**, **button3:**,
**button3:**, and **button4:** are reserved and have specific behaviors associated with them.

## EXAMPLE CODE

Here is a short snippet of **"songmachine code"** that
may serve as an example.  Hopefully the comments are descriptive.

``` ruby
# INTRO and CHORUS 0

    # the program is executed from the beginning of the file
    # as soon as the song is "loaded"

    start:
        CLEAR_LOOPER                    # clear the looper to start
        LOOP_VOLUME 63                  # set looper to a known volume
        SYNTH_VOLUME 0                  # turn the synth all the way down
        GUITAR_VOLUME 70                # set the guitar to a known volume
        SYNTH_PATCH Bass1               # pick a synth patch for later use
        GUITAR_EFFECT_NONE              # turn off all guitar effects
        BUTTON_COLOR 4,yellow           # make 4th button from bottom left yellow
        BUTTON_COLOR 1,orange,FLASH     # make the first button flashing orange
        DISPLAY 1,"INTRO"               # display the part of the song we are in
        DISPLAY 2,"sing intro"          # display instructions about what to do here

        # the machine "blocks" on button1-4 or loop labels.
        # it advances to the next "buttonN" if that button is
        # pressed, or "loop:" label if the looper cycles through
        # a loop ...

        # In this example you play the intro, and then when ready, press the
        # 1st button to start recording the chorus ....

    button1:                            # when you press button1 the following happens:
        LOOPER_TRACK 1                  # start the looper recording
        BUTTON_COLOR 1,red              # set the button to red to indicate recording
        DISPLAY 1,"CHOR0"               # display the part of the song we are in
        DISPLAY 2,"recording base clip" # display what's going on at this time

# LEAD 0 - Acoustic guitar fill thru base clip

        # once you press the button again, it starts playing the loop,
        # turns on the guitar echo so you can play lead over it ...

    button1:
        LOOPER_TRACK 1                  # end recording
        delay 10                        # 10's of a second to allow for good loop end recording
        GUITAR_EFFECT_ECHO on           # turn on the echo effect
        BUTTON_COLOR 1,green,FLASH      # change button to green flashing
        DISPLAY 1,"A-LEAD"              # display stuff ...
        DISPLAY 2,"play acc lead\nready bass"

        # ready bass - you press this button at the end of the
        # guitar lead but BEFORE the loop happens to fade
        # out the guitar and fade in the bass before recording it.

    button1:                            # press this BEFORE loop ends!
        BUTTON_COLOR 1,red,FLASH        # show red flashing button
        GUITAR_VOLUME 0,20              # bring guitar down over 2 seconds
        SYNTH_VOLUME 85,20              # while bringing synth up over two seconds
        DUB_MODE                        # set dub mode to ...
        LOOPER_TRACK 1                  # start recording on next loop
        DISPLAY 2,"ready record bass"

# VERSE1 and CHORUS1 - while recording bass

        # the next time the looper comes around, the song
        # machine will get the "loop" event and trigger
        # the following section of code ...

    loop:
        BUTTON_COLOR 1,red              # button to red
        DISPLAY 1,"VERSE1"              # what part of song are we in?
        DISPLAY 2,"recording bass1"     # what the heck are you supposed to be doing now!

    ... and so on

```

The above example lets you play an intro, then record a straight guitar part,
then play lead with echo over it, then start recording bass over that, with only two button
presses.  The chosen synth patch, volumes and guitar effects are determined by the code.
All you do is tell the machine **WHEN** to change state ...

----- end of readme_songmachine.md ------

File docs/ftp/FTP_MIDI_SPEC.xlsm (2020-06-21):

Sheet: raw_ftp_commans
RAW FTP COMMAND DATA
 | This data is visualized in the DISPLAY worksheet by setting parameters here, and pressing the refresh button.
 | 1F | name | reply | 3F | detail | descrip
 | 0x04 | EDITOR_MODE | both |  | 0 | Tuner On or Off (might do more)
 | 0x04 | EDITOR_MODE | cmd | 0x00 | 1 | Turn tuner OFF
 | 0x04 | EDITOR_MODE | cmd | 0x02 | 1 | Turn tuner ON
 | 0x04 | EDITOR_MODE | reply | 0x00 | 1 | Tuner is OFF
 | 0x04 | EDITOR_MODE | reply | 0x02 | 1 | Tuner is ON
 | 0x04 | EDITOR_MODE |  |  | 2 | For lack of a better term, I call this "editor" mode. Without this 0x02 you don't get the Tuning messages needed for the Tuner UI. Might better be called TUNER_MODE", though I suspect it is interpreted bitwise as a tri-state value.
 | 0x04 | EDITOR_MODE |  |  | 3 | The only parameters I know which "do" something are "0x02" which turns the tuner on, and 0x00 which turns the tuner off. I suspect there is more going on here than just tuning mode. When this message is sent the controller also may send out a slew of stuff, or it might not. It ppears as if the controller *may* track this state bitwise. and send out different message based on if the bits change. The controller also sends out some other 1f/3C replies, including unknown 0c, slider position 05, the ubiquitous unknown 55, unknown 1e, pitch bends on channel 1 & 2, another 55, and a 25 byte sysex with the current patch name.
 | 0x05 | SLIDER_POSITION | both |  | 0 | Slider Position
 | 0x05 | SLIDER_POSITION | cmd | 0x00 | 1 | Get Slider Position
 | 0x05 | SLIDER_POSITION | reply | nn | 1 | nn = 1,3,2 for the position of the slider
 | 0x05 | SLIDER_POSITION | reply | nn | 2 | Note that the slider positions are not in order and go from 1 = the slider is forward (closest to the soundhole) 3 = the slider is in the middle position 2 = the slider is at the rear (closest to the tailpiece)
 | 0x05 | SLIDER_POSITION | reply |  | 3 | The controller reports this on default startup, and it is part of the Editor startup conversation. Changing the slider position has the additional behavior of sending midi volume CC messages (Bn 07 xx) on channels 1 and 2 in poly mode, and 1-7 AND 11-16 in mono mode.
 | 0x06 | unknown |  |  | 99
 | 0x07 | BATTERY_LEVEL | both |  | 0 | Battery Level
 | 0x07 | BATTERY_LEVEL | cmd | 0x00 | 1 | Get Battery Level
 | 0x07 | BATTERY_LEVEL | reply | nn | 1 | Battery Level Reply (0x40 to 0x6F)
 | 0x07 | BATTERY_LEVEL | reply |  | 2 | The battery level return value nn is believed to be from 0x40 to 0x6f. In the FTP editor It changes to red at 0x4b and is green at or above 0x4c, and It shows full at 0x63. There is always at least one red line (min) at 0x43 or below.
 | 0x08 | VOLUME_LEVEL | both |  | 0 | Get Volume Level
 | 0x09 | unknown |  |  | 99
 | 0x0A | unknown |  |  | 99
 | 0x0B | unknown |  |  | 99
 | 0x0C | unknown |  |  | 0 | controller sends this at startup
 | 0x0D | unknown |  |  | 99
 | 0x0E | unknown |  |  | 99
 | 0x0F | unknown |  |  | 99
 | 0x10 | unknown |  |  | 99
 | 0x11 | unknown |  |  | 99
 | 0x12 | unknown |  |  | 99
 | 0x13 | unknown |  |  | 99
 | 0x14 | unknown |  |  | 99
 | 0x15 | unknown |  |  | 99
 | 0x16 | unknown |  |  | 99
 | 0x17 | unknown |  |  | 99
 | 0x18 | unknown |  |  | 99
 | 0x19 | unknown |  |  | 99
 | 0x1A | unknown |  |  | 99
 | 0x1B | unknown |  |  | 99
 | 0x1C | unknown |  |  | 99
 | 0x1D | unknown |  |  | 99
 | 0x1E | unknown |  |  | 0 | controller sends this at startup
 | 0x1F | unknown |  |  | 99

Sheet: display_ftp_commands
FTP 1F/3F COMMANDS
 | These commands are sent and received as a series of two reserved CC midi messages (1F and 3F)
 | Typically the FTP editor sends a "command" and typically the FTP controller replies with a "reply"
 | The commands are sent and received as "B7", which is a continuous controller on midi channel
 | A simple example shows the editor asking for the position of the "slider" switch on the controller:
 |  | editor sends | B7 1F 05 |  | 05 = command "GET_SLIDER_POSITION"
 |  |  | B7 3F 00 |  | 00 = command parameter
 |  | controller replies | B7 1F 05 |  | 05 = reply "SLIDER_POSITION"
 |  |  | B7 3F 02 |  | 02 = the slider is towards the tailpiece of the guitar
 |  | detail level: | 3
 |  | show unknown | 1
 | 1F | name | reply | 3F | descrip
 | 0x04 | EDITOR_MODE | both |  | Tuner On or Off (might do more)
 |  |  | cmd | 0x00 | Turn tuner OFF
 |  |  |  | 0x02 | Turn tuner ON
 |  |  | reply | 0x00 | Tuner is OFF
 |  |  |  | 0x02 | Tuner is ON
 |  |  |  |  | For lack of a better term, I call this "editor" mode. Without this 0x02 you don't get the Tuning messages needed for the Tuner UI. Might better be called TUNER_MODE", though I suspect it is interpreted bitwise as a tri-state value.
 |  |  |  |  | The only parameters I know which "do" something are "0x02" which turns the tuner on, and 0x00 which turns the tuner off. I suspect there is more going on here than just tuning mode. When this message is sent the controller also may send out a slew of stuff, or it might not. It ppears as if the controller *may* track this state bitwise. and send out different message based on if the bits change. The controller also sends out some other 1f/3C replies, including unknown 0c, slider position 05, the ubiquitous unknown 55, unknown 1e, pitch bends on channel 1 & 2, another 55, and a 25 byte sysex with the current patch name.
 | 0x05 | SLIDER_POSITION | both |  | Slider Position
 |  |  | cmd | 0x00 | Get Slider Position
 |  |  | reply | nn | nn = 1,3,2 for the position of the slider
 |  |  |  |  | Note that the slider positions are not in order and go from 1 = the slider is forward (closest to the soundhole) 3 = the slider is in the middle position 2 = the slider is at the rear (closest to the tailpiece)
 |  |  |  |  | The controller reports this on default startup, and it is part of the Editor startup conversation. Changing the slider position has the additional behavior of sending midi volume CC messages (Bn 07 xx) on channels 1 and 2 in poly mode, and 1-7 AND 11-16 in mono mode.
 | 0x07 | BATTERY_LEVEL | both |  | Battery Level
 |  |  | cmd | 0x00 | Get Battery Level
 |  |  | reply | nn | Battery Level Reply (0x40 to 0x6F)
 |  |  |  |  | The battery level return value nn is believed to be from 0x40 to 0x6f. In the FTP editor It changes to red at 0x4b and is green at or above 0x4c, and It shows full at 0x63. There is always at least one red line (min) at 0x43 or below.
 | 0x08 | VOLUME_LEVEL | both |  | Get Volume Level
 | 0x0C | unknown |  |  | controller sends this at startup
 | 0x1E | unknown |  |  | controller sends this at startup

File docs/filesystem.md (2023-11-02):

# The FAT32 fileSystem

This page describes the **fileSystem**.

The fileSystem is currently ONLY *used* by the [**songMachine**](songmachine.md) to
read **.song** files from the */songs* directory on the SD card.

The fileSystem also presents a *Serial File Transfer Protocol*, which
allows one to transmit, retrieve, rename, and delete files anywhere on the SD
card, over *either* the main teensy 3.6 USB Serial Port *OR* the serial port
presented on the back of the teensyExpression as a 1/8" jack, depending
on the configSystem setting of the **System-File System Port** preference.

## API for use by program

Once initialized (by *expSystem.cpp*) clients make use of the
*SdFat* API, specifically, that of the global *SdFatSdio* **"SD"** and *File* objects
therein.

For example, here's how you open and read a file:

```c++
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

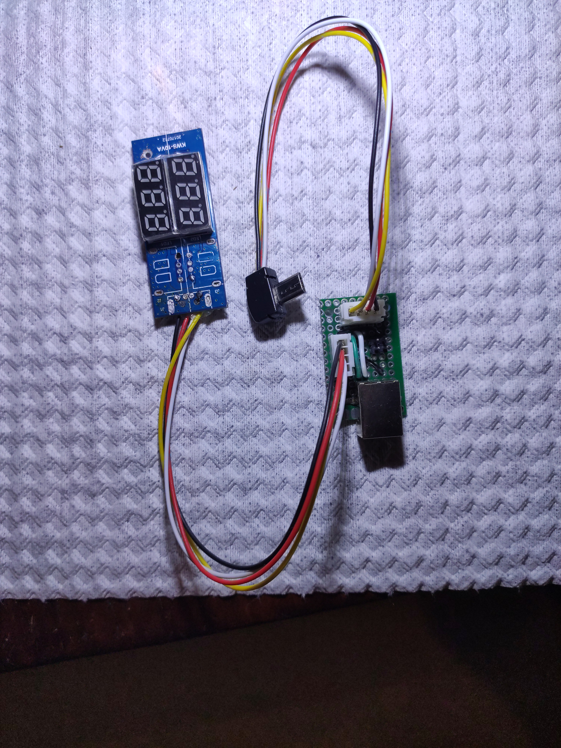
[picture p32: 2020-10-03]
docs/images/hardware-power_meter_wired.big.jpg

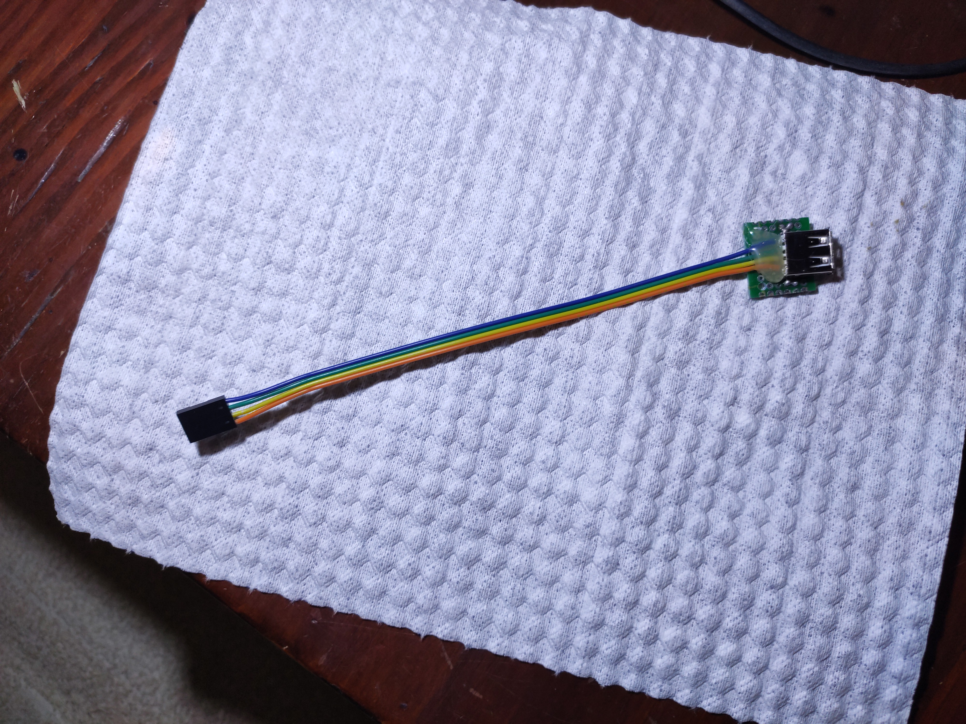
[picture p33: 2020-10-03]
docs/images/hardware-host_port.big.jpg

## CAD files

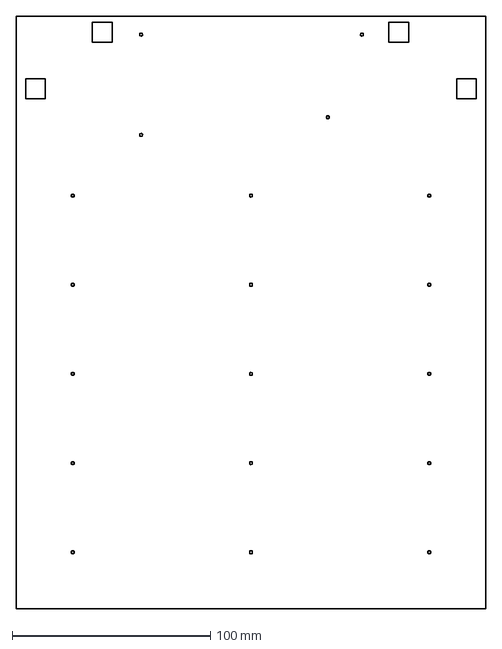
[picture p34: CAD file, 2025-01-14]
docs/fusion/base.dxf
237.0 x 299.0 mm

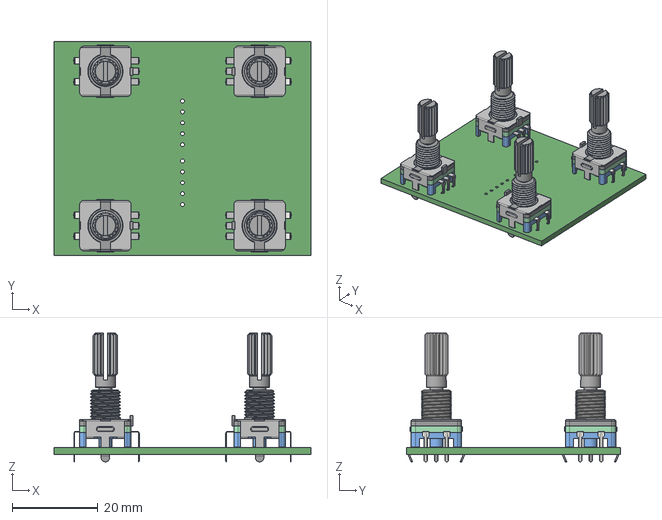
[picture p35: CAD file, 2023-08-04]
docs/kicad/rotary_board/rotary_board.step
60.0 x 50.0 x 30.1 mm

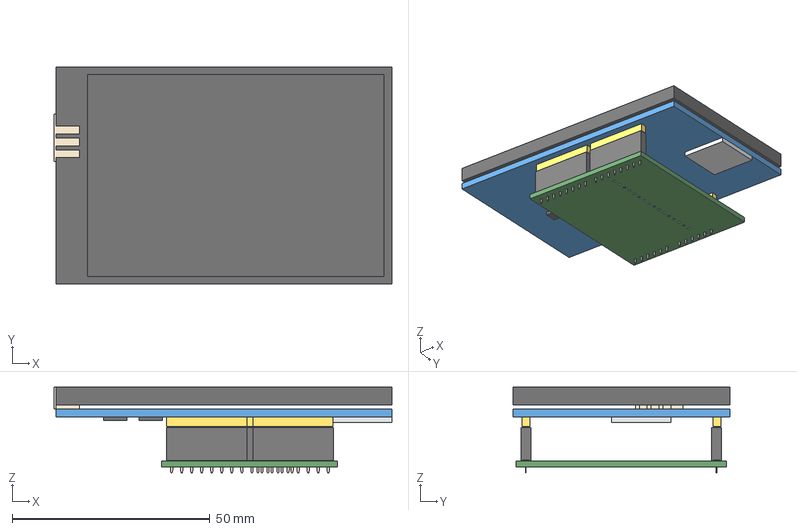
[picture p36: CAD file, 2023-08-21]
docs/kicad/uno_display_connector/uno_display_connector.step
85.5 x 55.0 x 21.7 mm

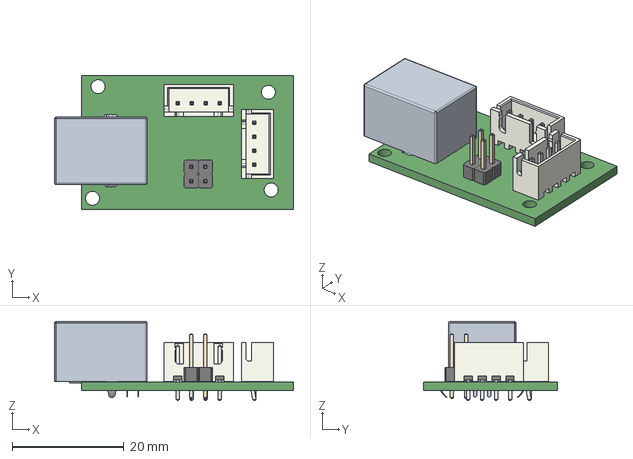
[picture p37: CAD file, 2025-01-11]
docs/kicad/usb_board/usb_board.step
42.8 x 24.0 x 14.2 mm

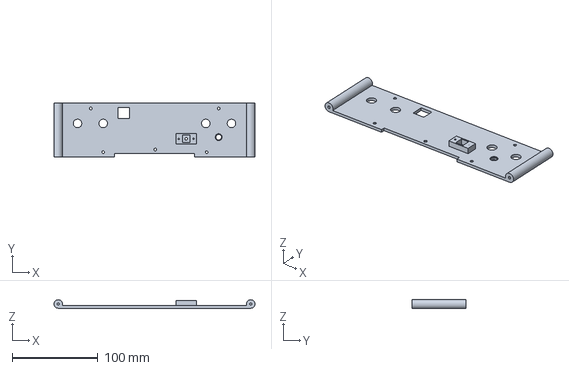
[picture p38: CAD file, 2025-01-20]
docs/prusa/back.3mf
235.0 x 62.9 x 10.00 mm

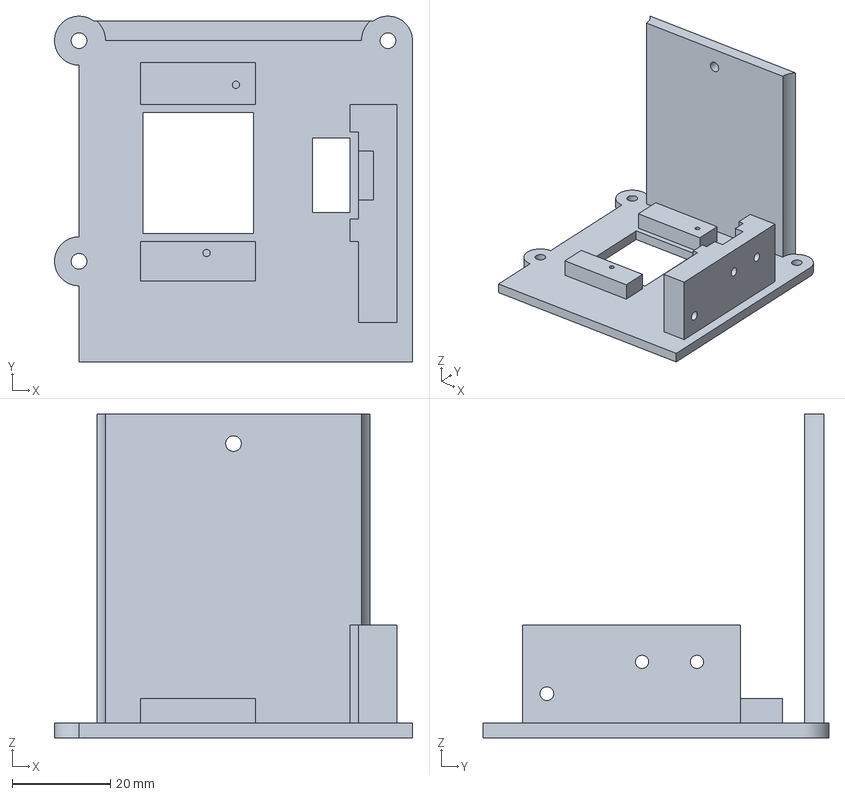
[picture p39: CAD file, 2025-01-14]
docs/prusa/top_right.3mf
73.0 x 70.5 x 66.0 mm

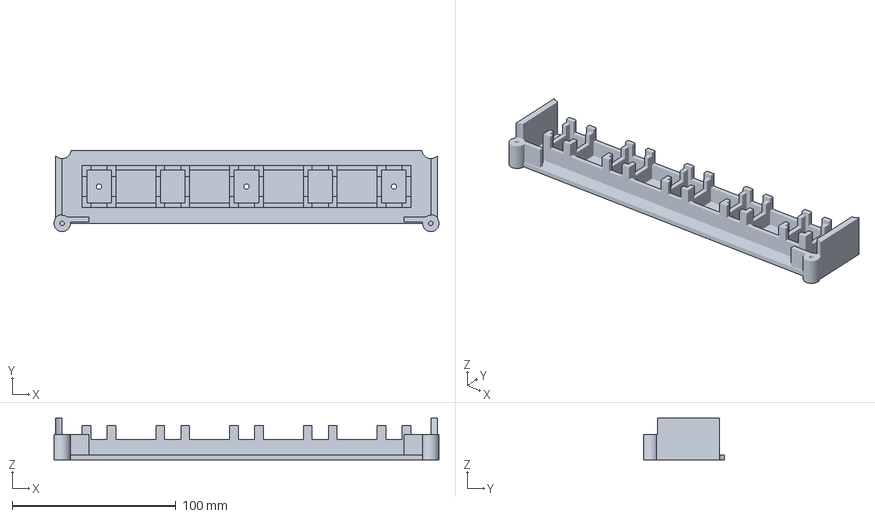
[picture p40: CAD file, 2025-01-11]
docs/prusa/frame2.3mf
235.0 x 49.6 x 25.5 mm

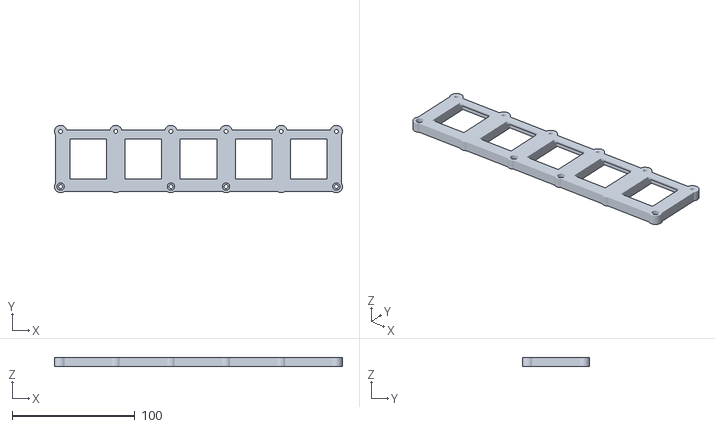
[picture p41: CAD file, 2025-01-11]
docs/stl/top1.stl
235.0 x 55.0 x 7.50

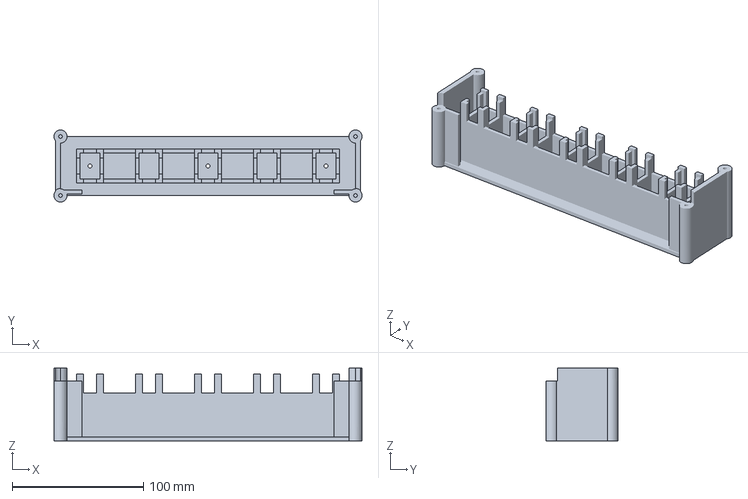
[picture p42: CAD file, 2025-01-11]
docs/prusa/frame5.3mf
235.0 x 55.0 x 55.5 mm

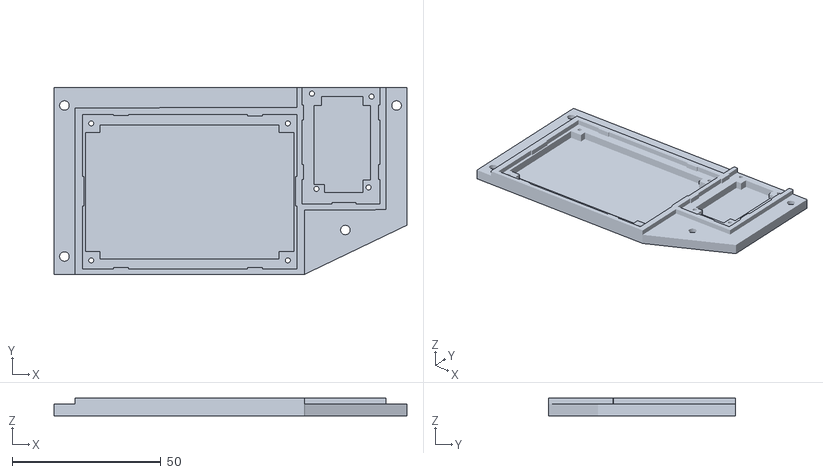
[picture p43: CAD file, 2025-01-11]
docs/stl/pcb_base.stl
118.5 x 62.7 x 6.00

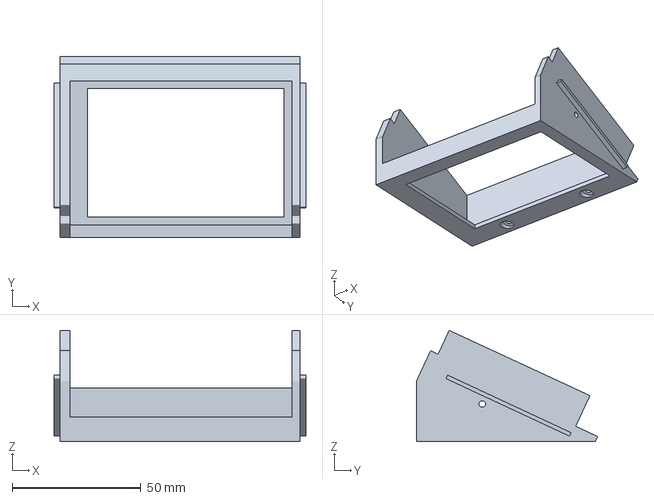
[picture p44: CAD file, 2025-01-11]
docs/prusa/display_case.3mf
98.0 x 70.5 x 43.3 mm

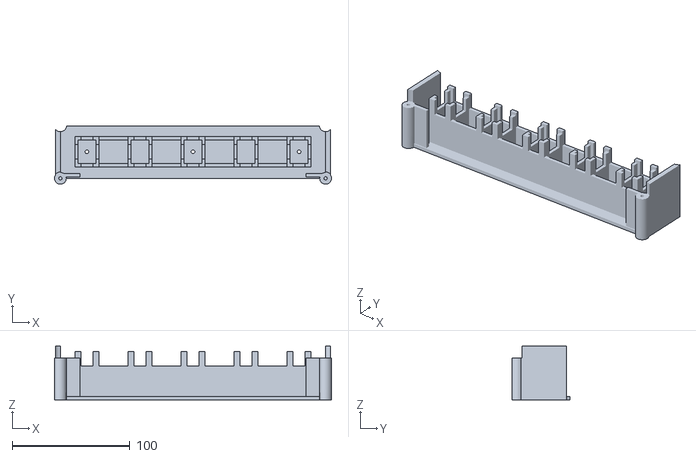
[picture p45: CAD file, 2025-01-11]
docs/stl/frame4.stl
235.0 x 49.6 x 45.5

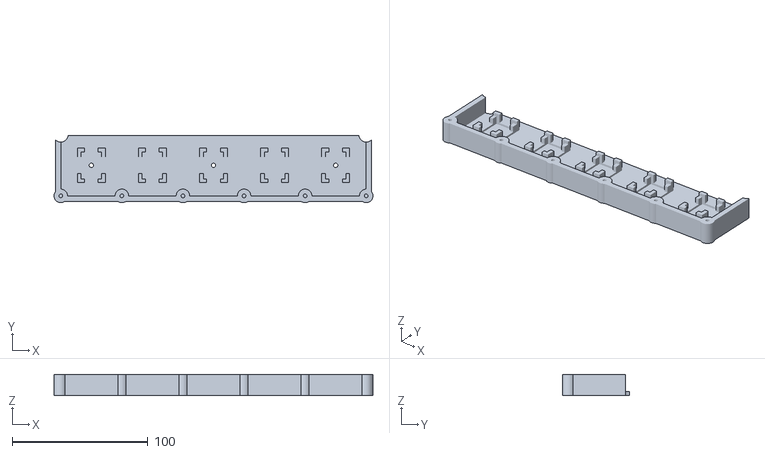
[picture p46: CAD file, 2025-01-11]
docs/stl/frame1.stl
235.0 x 49.6 x 15.5

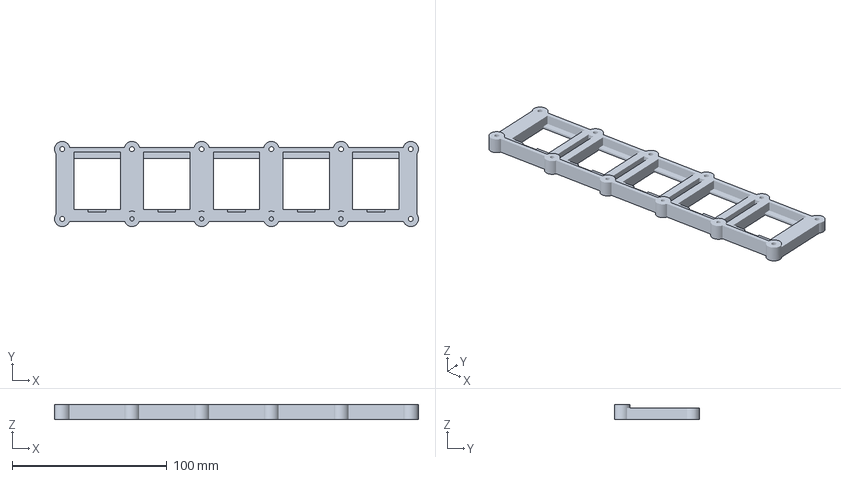
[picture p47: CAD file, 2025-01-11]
docs/prusa/top_middle.3mf
235.0 x 55.0 x 9.80 mm

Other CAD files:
docs/stl/back.stl
docs/stl/top_right.stl
docs/prusa/pcb_base.3mf
docs/stl/display_case.stl
docs/prusa/button_base_x_5.3mf
docs/prusa/button_hinge_x_27.3mf
docs/prusa/button_top_x_5.3mf
docs/prusa/display_insert.3mf
docs/prusa/frame1.3mf
docs/prusa/frame3.3mf
docs/prusa/frame4.3mf
docs/prusa/generic_screw_fastener_x_4.3mf
docs/prusa/top1.3mf
docs/prusa/top5.3mf
docs/prusa/top_left.3mf
docs/stl/display_insert.stl
docs/stl/frame2.stl
docs/stl/frame3.stl
docs/stl/frame5.stl
docs/stl/generic_screw_fastener.stl
docs/stl/top5.stl
docs/stl/top_left.stl
docs/stl/top_middle.stl

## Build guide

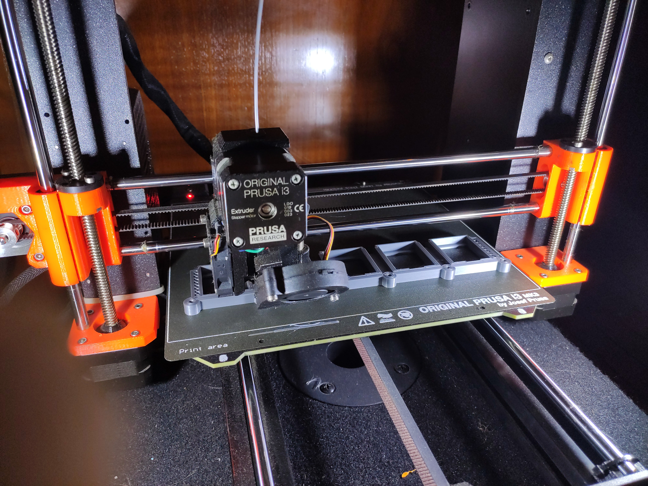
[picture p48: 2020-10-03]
docs/images/3d-printing.big.jpg

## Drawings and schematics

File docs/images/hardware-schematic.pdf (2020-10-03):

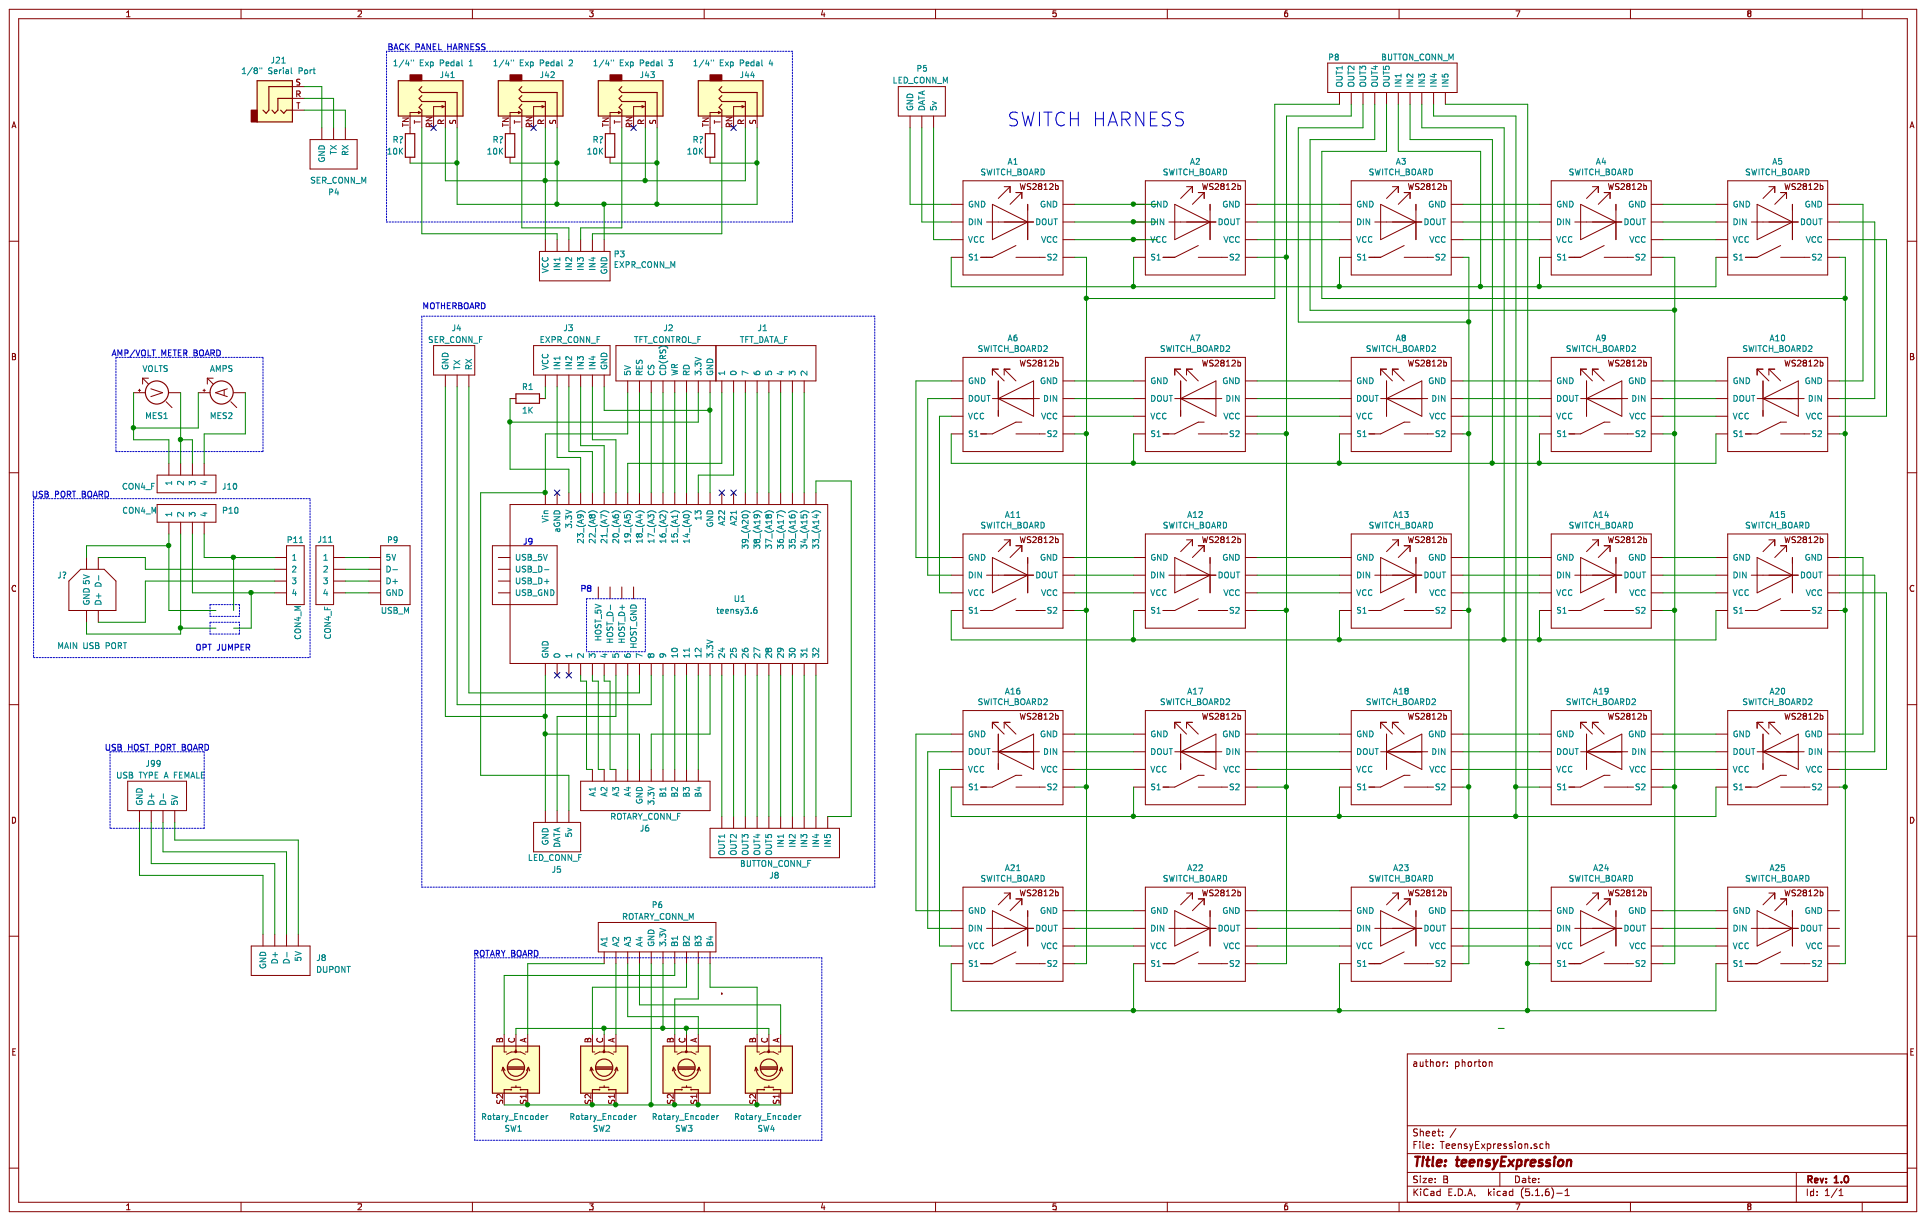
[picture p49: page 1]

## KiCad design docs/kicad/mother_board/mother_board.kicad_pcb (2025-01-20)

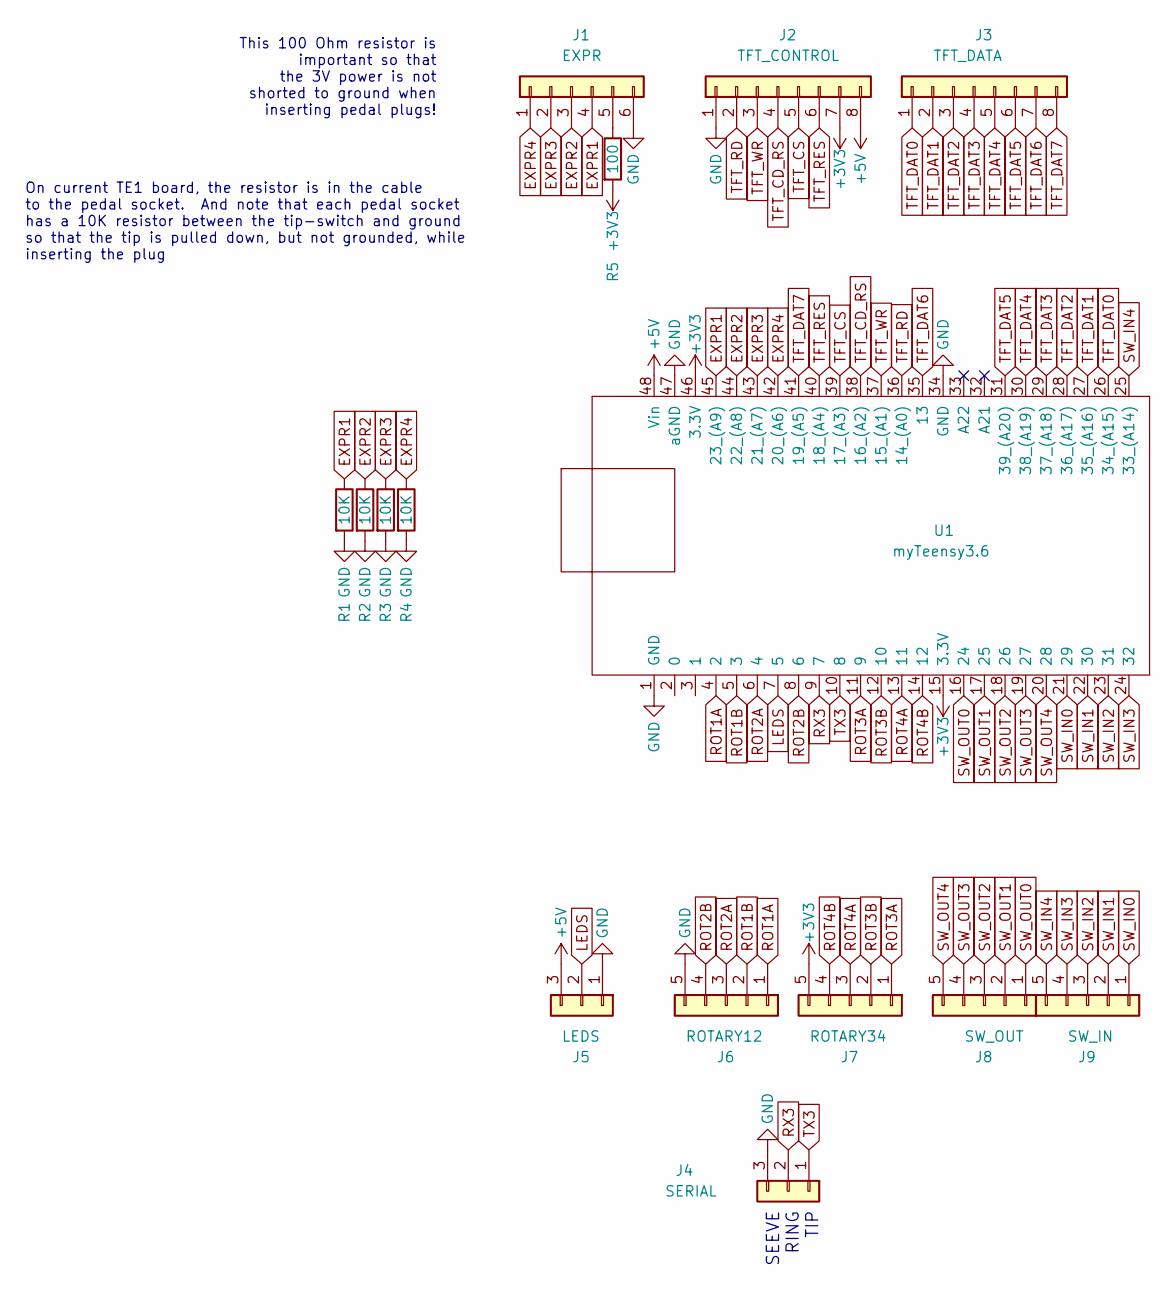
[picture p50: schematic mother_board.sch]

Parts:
J1: EXPR; myPinSocket_1x06
J2: TFT_CONTROL; myJSTx08
J3: TFT_DATA; myJSTx08
J4: SERIAL; myPinSocket_1x03
J5: LEDS; myPinSocket_1x03
J6: ROTARY12; myPinSocket_1x05
J7: ROTARY34; myPinSocket_1x05
J8: SW_OUT; myPinSocket_1x05
J9: SW_IN; myPinSocket_1x05
R1, R2, R3, R4: 10K; myResistor
R5: 100; myResistor
U1: myTeensy3.6

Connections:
+3V3: J2.7, J7.5, R5.2, U1.15 (3.3V), U1.46 (3.3V)
+5V: J2.8, J5.3, U1.48 (Vin)
EXPR1: J1.4, R1.1, U1.45 (23_(A9))
EXPR2: J1.3, R2.1, U1.44 (22_(A8))
EXPR3: J1.2, R3.1, U1.43 (21_(A7))
EXPR4: J1.1, R4.1, U1.42 (20_(A6))
GND: J1.6, J2.1, J4.3, J5.1, J6.5, R1.2, R2.2, R3.2, R4.2, U1.1 (GND), U1.34 (GND), U1.47 (aGND)
LEDS: J5.2, U1.7 (5)
unnamed: J1.5, R5.1
ROT1A: J6.1, U1.4 (2)
ROT1B: J6.2, U1.5 (3)
ROT2A: J6.3, U1.6 (4)
ROT2B: J6.4, U1.8 (6)
ROT3A: J7.1, U1.11 (9)
ROT3B: J7.2, U1.12 (10)
ROT4A: J7.3, U1.13 (11)
ROT4B: J7.4, U1.14 (12)
RX3: J4.2, U1.9 (7)
SW_IN0: J9.1, U1.21 (29)
SW_IN1: J9.2, U1.22 (30)
SW_IN2: J9.3, U1.23 (31)
SW_IN3: J9.4, U1.24 (32)
SW_IN4: J9.5, U1.25 (33_(A14))
SW_OUT0: J8.1, U1.16 (24)
SW_OUT1: J8.2, U1.17 (25)
SW_OUT2: J8.3, U1.18 (26)
SW_OUT3: J8.4, U1.19 (27)
SW_OUT4: J8.5, U1.20 (28)
TFT_CD_RS: J2.4, U1.38 (16_(A2))
TFT_CS: J2.5, U1.39 (17_(A3))
TFT_DAT0: J3.1, U1.26 (34_(A15))
TFT_DAT1: J3.2, U1.27 (35_(A16))
TFT_DAT2: J3.3, U1.28 (36_(A17))
TFT_DAT3: J3.4, U1.29 (37_(A18))
TFT_DAT4: J3.5, U1.30 (38_(A19))
TFT_DAT5: J3.6, U1.31 (39_(A20))
TFT_DAT6: J3.7, U1.35 (13)
TFT_DAT7: J3.8, U1.41 (19_(A5))
TFT_RD: J2.2, U1.36 (14_(A0))
TFT_RES: J2.6, U1.40 (18_(A4))
TFT_WR: J2.3, U1.37 (15_(A1))
TX3: J4.1, U1.10 (8)

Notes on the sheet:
SEEVE RING TIP
This 100 Ohm resistor is important so that the 3V power is not shorted to ground when inserting pedal plugs!
On current TE1 board, the resistor is in the cable to the pedal socket. And note that each pedal socket has a 10K resistor between the tip-switch and ground so that the tip is pulled down, but not grounded, while inserting the plug

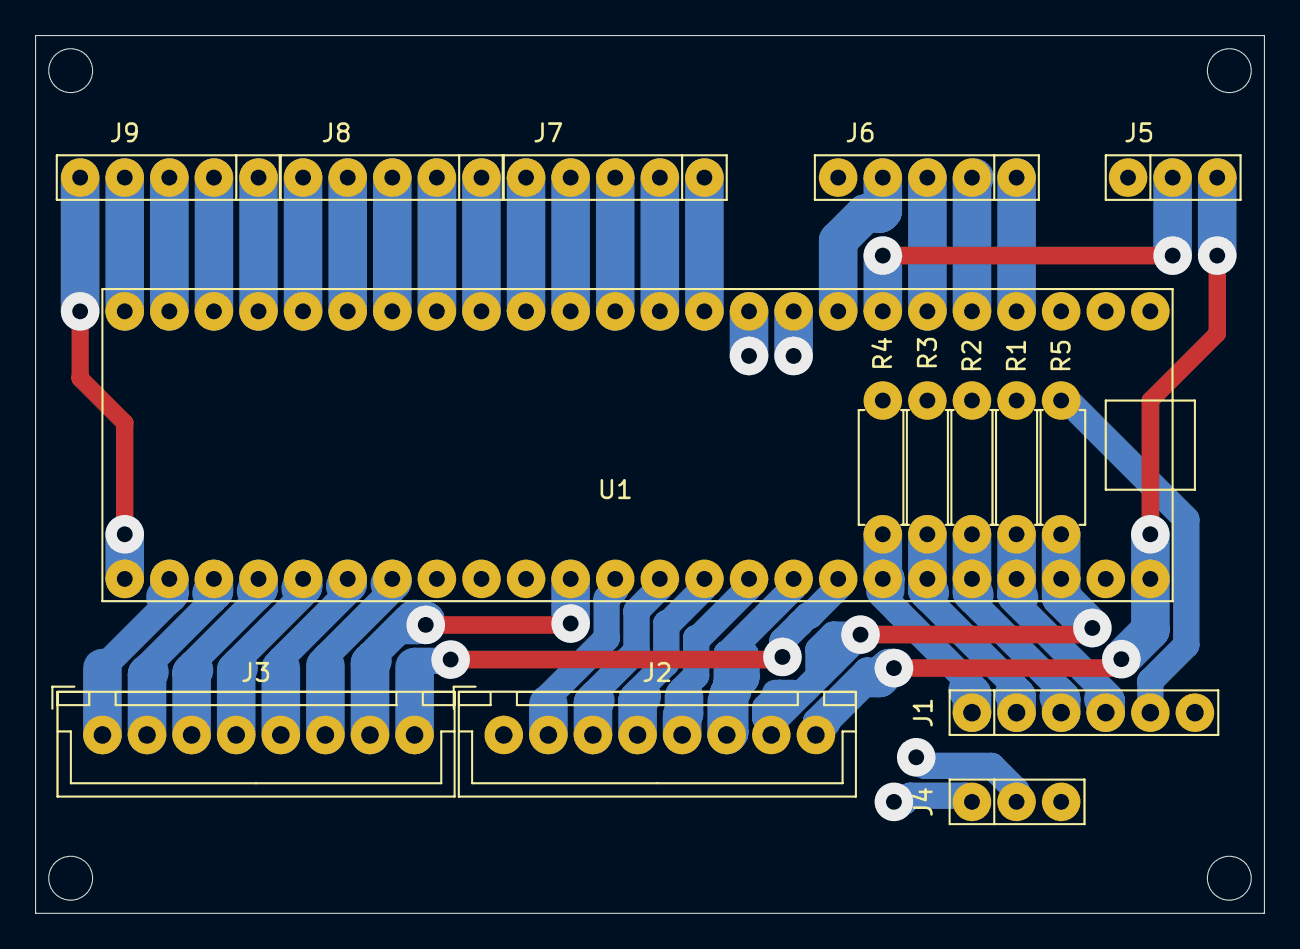
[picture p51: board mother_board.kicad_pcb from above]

Board: 2 copper layers, 70.0 x 50.0 mm, 15 parts (0 on the bottom side), 42 nets.

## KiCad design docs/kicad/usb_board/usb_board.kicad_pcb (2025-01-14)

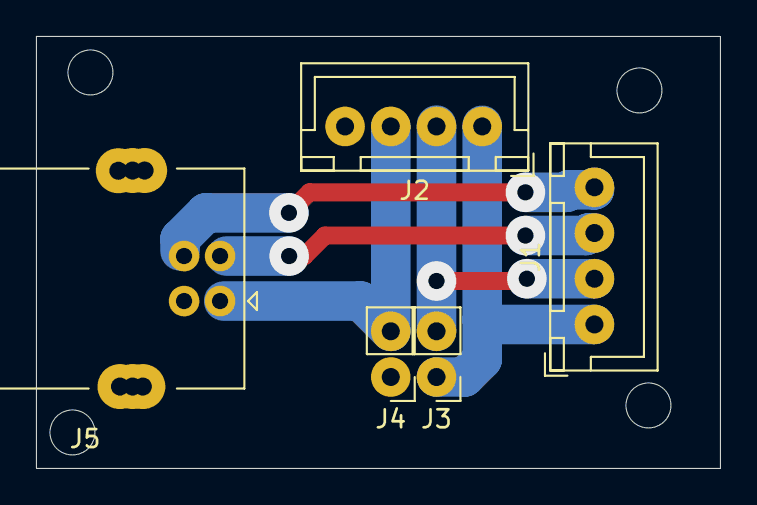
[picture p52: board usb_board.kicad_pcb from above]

Board: 2 copper layers, 38.0 x 24.0 mm, 5 parts (0 on the bottom side), 6 nets.

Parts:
J1: USB_OUT; myJSTx04
J2: PWR_IO; myJSTx04
J3: JUMP_OUT; myPinHeader_1x02
J4: JUMP_IN; myPinHeader_1x02
J5: myUSB_B_Socket

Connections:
+5V: J2.3, J4.2, J5.1
D+: J1.4, J5.3
D-: J1.3, J5.2
GND: J2.4, J4.1, J5.4
unnamed: J1.1, J2.1, J3.1
unnamed: J1.2, J2.2, J3.2

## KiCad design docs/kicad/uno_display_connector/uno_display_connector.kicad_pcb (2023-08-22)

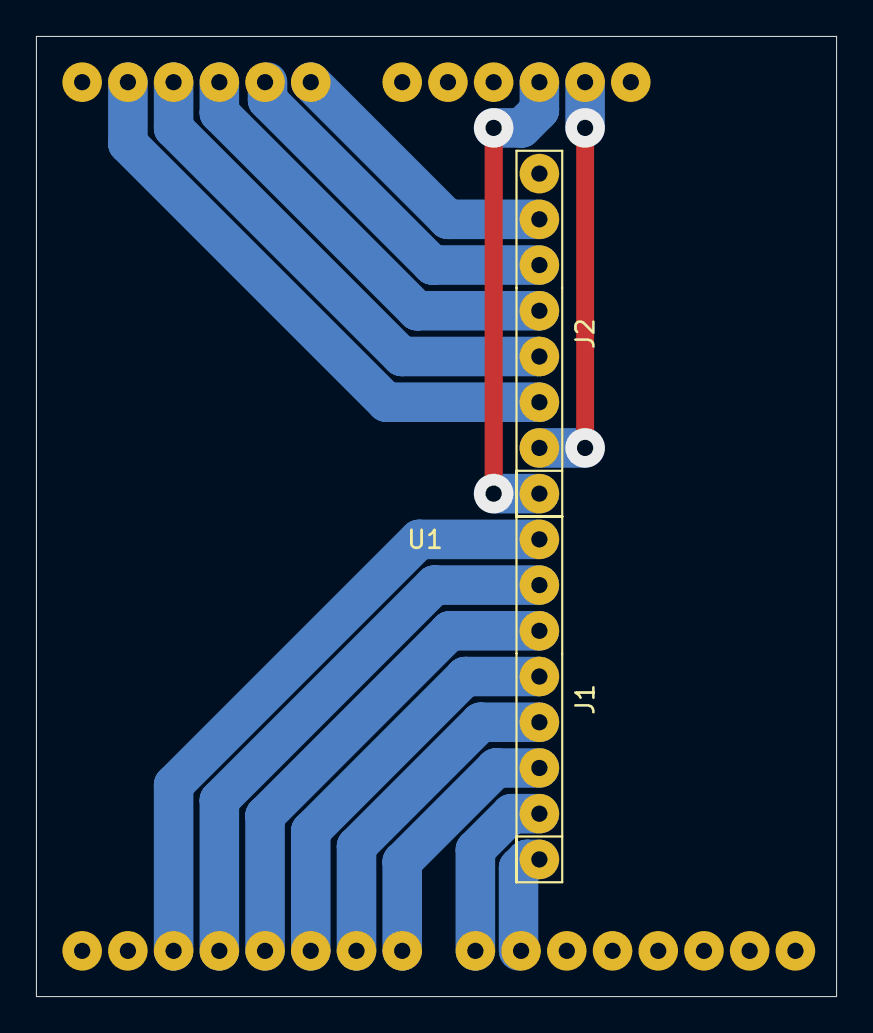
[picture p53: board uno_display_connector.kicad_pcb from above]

Board: 2 copper layers, 44.5 x 53.3 mm, 3 parts (0 on the bottom side), 16 nets.

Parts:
J1, J2: Conn_01x08; my8Pin
U1: uno_display; unoDisplay

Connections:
+3V3: J2.2, U1.18
+5V: J2.1, U1.19
GND: J2.8, U1.21
LCD_CS: J2.4, U1.26
LCD_D0: J1.2, U1.9
LCD_D1: J1.1, U1.10
LCD_D2: J1.8, U1.3
LCD_D3: J1.7, U1.4
LCD_D4: J1.6, U1.5
LCD_D5: J1.5, U1.6
LCD_D6: J1.4, U1.7
LCD_D7: J1.3, U1.8
LCD_RD: J2.7, U1.23
LCD_RS: J2.5, U1.25
LCD_RST: J2.3, U1.27
LCD_WR: J2.6, U1.24

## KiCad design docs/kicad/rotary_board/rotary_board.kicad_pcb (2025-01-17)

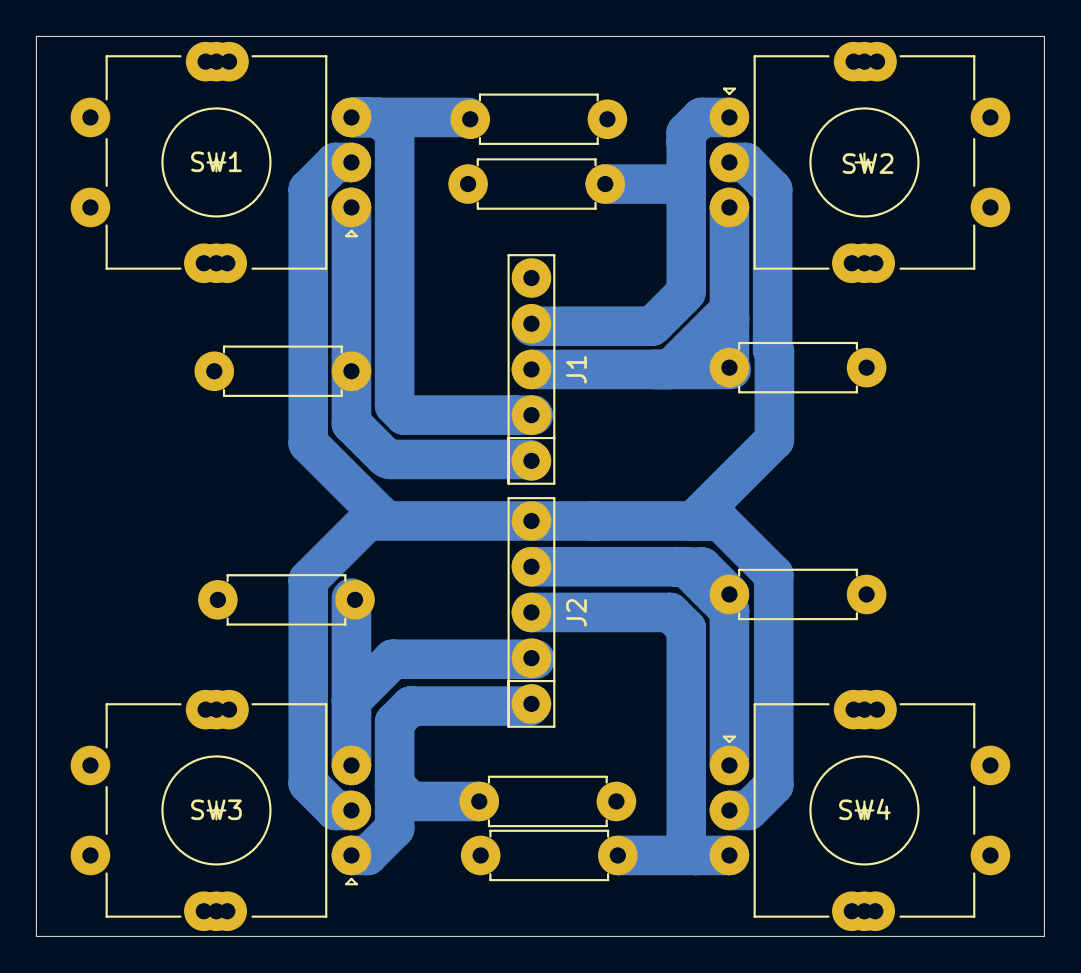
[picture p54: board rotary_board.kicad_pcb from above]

Board: 2 copper layers, 56.0 x 50.0 mm, 14 parts (0 on the bottom side), 10 nets.

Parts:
J1: ROTARY12; my5Pin
J2: ROTARY34; my5Pin
R1, R2, R3, R4, R5, R6, R7, R8: 10K; myResistor
SW1, SW2, SW3, SW4: Rotary_Encoder_Switch; myRotaryEncoder

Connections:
+3V3: J2.5, SW1.C, SW2.C, SW3.C, SW4.C
GND: J1.5, R1.2, R2.2, R3.2, R4.2, R5.2, R6.2, R7.2, R8.2, SW1.S1, SW1.S2, SW2.S1, SW2.S2, SW3.S1, SW3.S2, SW4.S1, SW4.S2
ROT1A: J1.1, R2.1, SW1.A
ROT1B: J1.2, R1.1, SW1.B
ROT2A: J1.4, R3.1, SW2.A
ROT2B: J1.3, R4.1, SW2.B
ROT3A: J2.1, R5.1, SW3.A
ROT3B: J2.2, R6.1, SW3.B
ROT4A: J2.4, R8.1, SW4.A
ROT4B: J2.3, R7.1, SW4.B

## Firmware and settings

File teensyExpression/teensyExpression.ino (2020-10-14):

// teensyExpression.ino


#include <myDebug.h>
#include "prefs.h"
#include "myTFT.h"
#include "myLeds.h"
#include "pedals.h"
#include "rotary.h"
#include "buttons.h"
#include "expSystem.h"
#include "myMidiHost.h"
#include "myTouchScreen.h"



#define TOUCH_DRAW_TEST  0


//-----------------------------------------------------------
// setup
//-----------------------------------------------------------


extern "C" {
    extern void setFishmanFTPDescriptor();
    extern void my_usb_init();          // in usb_dev.c
}


void setup()
{
    init_global_prefs();

    // start the hardware serial port

    Serial3.begin(115200);
    elapsedMillis serial_started = 0;
    while (serial_started<1000 && !Serial3) {}

    #if 1
        if (Serial3)
        {
            delay(1000);
            Serial3.println("hello from teensyExpression Serial3 port");
        }
    #endif

    // Turn off display() and the like
    // The ports will still be opened even if nothing goes
    // to them.  This may add to startup time if nobody is
    // there to open them ..

    uint8_t serial_debug_pref = getPref8(PREF_DEBUG_PORT);
    if (serial_debug_pref == 2)
    {
        dbgSerial = &Serial3;
        display(0,"debugging output redirected to Serial3",0);
    }
    else if (!serial_debug_pref)
    {
        dbgSerial = 0;      // yikes!
    }

    // start the teensyDuino (self) USB device

    if (getPref8(PREF_SPOOF_FTP))
        setFishmanFTPDescriptor();
    my_usb_init();
    delay(1000);

    // initialize the main (debugging) serial port

    Serial.begin(115200);
    serial_started = 0;
    while (serial_started<1000 && !Serial) {}

    delay(400);
    display(0,"teensyExpression v2.01 started",0);

    // start the TFT display device

    initMyTFT();

    mylcd.Set_Text_Back_colour(0);
    mylcd.Set_Text_colour(TFT_WHITE);
    mylcd.setFont(Arial_16);
    mylcd.Set_Text_Cursor(5,5);
    mylcd.println("teensyExpression started ... ");

    int do_delay = 0;

    if (!dbgSerial)
    {
        mylcd.Set_Text_colour(TFT_YELLOW);
        mylcd.println("    NO SERIAL PORT IS ACTIVE!!");
        do_delay = 3000;
    }
    else if (serial_debug_pref == 2)
    {
        mylcd.Set_Text_colour(TFT_YELLOW);
        mylcd.println("    DEBUG_OUTPUT to hardware Serial3!");
        if (!do_delay) do_delay = 1200;
    }

    #if !defined(USB_MIDI4_SERIAL)
        error("PROGRAM IS NOT COMPILED UNDER USB_MIDI4_SERIAL teensyDuino type!! Things may not work correctly!!!",0);
        mylcd.Set_Text_colour(TFT_YELLOW);
        mylcd.println("    NOT COMPILED WITH USB_MIDI4_SERIAL !!");
        do_delay = 5000;
    #endif

    if (do_delay)
        delay(do_delay);

    // start myMidihost

    midi_host.init();

    // and the rest of the stuff

    display(0,"initializing system ...",0);

    initLEDs();
    clearLEDs();
    showLEDs();
    theSystem.begin();

    display(0,"system running ...",0);

}   // setup()




//-----------------------------------------
// loop
//-----------------------------------------

void loop()
{
    theSystem.updateUI();
        // see expSystem.cpp

    #if TOUCH_DRAW_TEST

        // if I don't assume a "release" for at least 350 or so ms
        // after a "press", then I can implement swipe gestures.

        static bool cleared = 0;
        static elapsedMillis clear_it = 0;
        if (!cleared && clear_it > 350)
        {
            mylcd.Fill_Screen(0);
            clear_it = 0;
            cleared = 1;
        }

        int x,y,z;
        theTouchScreen.get(&z,&x,&y);
        if (z)
        {
            cleared = 0;
            clear_it = 0;
            mylcd.setDefaultFont();
            mylcd.Set_Text_Size(3);
            mylcd.Print_String("o",x,y);
        }

    #endif

}   // loop()

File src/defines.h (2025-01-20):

//--------------------------------
// defines.h
//--------------------------------

#pragma once

#define TEENSY_EXPRESSION_VERSION  "v1.1"

#define SERIAL_DEVICE	   Serial3
	// the serial port to use for our 'Serial' device

// "compatability layer" for fileXXX.h and cpp
// which are normalized between TE1 and TE2

#define ACTIVE_FILE_SYS_DEVICE ((getPref8(PREF_FILE_SYSTEM_PORT) == FILE_SYS_DEVICE_SERIAL) ? \
	((Stream *)&SERIAL_DEVICE) : \
	((Stream *)&Serial))
extern "C" {
	extern const char *getUSBSerialNum();	// usb_desc.c
}


// TE1 specific defines

#define NUM_PORTS           8       // ports defined in midiQueue.h
#define NUM_PEDALS          4
#define NUM_BUTTON_COLS     5
#define NUM_BUTTON_ROWS     5
#define NUM_MIDI_PORTS      8

#define THE_SYSTEM_BUTTON   4

#define NUM_BUTTONS        (NUM_BUTTON_COLS * NUM_BUTTON_ROWS)
#define BUTTON_NUM(r,c)    ((r) * NUM_BUTTON_COLS + (c))
#define BUTTON_ROW(i)      ((i) / NUM_BUTTON_COLS)
#define BUTTON_COL(i)      ((i) % NUM_BUTTON_COLS)

#define BUTTON_MOVE_UP          12
#define BUTTON_MOVE_LEFT        16
#define BUTTON_MOVE_RIGHT       18
#define BUTTON_MOVE_DOWN        22
#define BUTTON_SELECT           17

#define PEDAL_SYNTH     0
#define PEDAL_LOOP      1
#define PEDAL_WAH       2
#define PEDAL_GUITAR    3

#define LOOPER_NUM_TRACKS_TIMES_LAYERS    (LOOPER_NUM_TRACKS * LOOPER_NUM_LAYERS)


typedef struct
    // structure common to New and Old rig patches
{
    int prog_num;
    const char *short_name;         // SHOULD BE 6 CHARS OR LESS
    const char *long_name;          // NOT USED IN NEW RIG
    bool mono_mode;                 // NOT USED IN OLD RIG
}   synthPatch_t;



//----------------------------------------------------------------------
// PIN USAGE
//----------------------------------------------------------------------
// On Teensy 3.6 SERIAL is SERIAL3
// On Teensy 4.1 SERIAL is SERIAL2

// left/right
//   pin
//    GND
// L  0        unused1 RX1 used by LEDS
// L  1        unused2 TX1 used by LEDS
// L  2        ROTARY_1A
// L  3        ROTARY_1B
// L  4        ROTARY_2A
// L  5        LEDS_OUT (Serial1)
// L  6        ROTARY_2B
// L  7        SERIAL_RX
// L  8        SERIAL_TX
// L  9        ROTARY_3A
// L 10        ROTARY_3B
// L 11        ROTARY_4A
// L 12        ROTARY_4B
//   3.3V
// L 24        BUTTON_OUT0
// L 25        BUTTON_OUT1
// L 26        BUTTON_OUT2
// L 27        BUTTON_OUT3
// L 28        BUTTON_OUT4
// L 29        BUTTON_IN0
// L 30        BUTTON_IN1
// L 31 A12    BUTTON_IN2
// L 32 A13    BUTTON_IN3
//      5V
//      AGND
//      GND
// R 23 A9     EXPR1
// R 22 A8     EXPR2
// R 21 A7     EXPR3
// R 20 A6     EXPR4
// R 19 A5     TFT_DATA7
// R 18 A4     TFT_RESET
// R 17 A3     TFT_CS
// R 16 A2     TFT_CD(RS)
// R 15 A1     TFT_WR
// R 14 A0     TFT_RD
// R 13        TFT_DATA6
//      3,3V
// R    A22    x - unused analog only;
// R    A21    x - unused analog only;
// R 39 A20    TFT_DATA5
// R 38 A19    TFT_DATA4
// R 37 A18    TFT_DATA3
// R 36 A17    TFT_DATA2
// R 35 A16    TFT_DATA1
// R 34 A15    TFT_DATA0
// R 33 A14    BUTTON_IN4


//============================================================
// pin definitions and connectors
//============================================================
// The serial cable connector, 3 pin Dupon on front of PCB, pins are facing.
//      On Teensy 3.6 SERIAL is SERIAL3
//      On Teensy 4.1 SERIAL is SERIAL2
// In terms of the teensy's viewpoint of RX/TX,
// which map to Tip, Ring, and Sleeve the opposite
// of the Looper's.

// SERIAL_TX    pin 1		// Tip on TE
// SERIAL_RX	pin 2		// Ring on TE
// GND          pin 3		// Sleeve on both


//--------------------------------------------
// Button in and out pins
//--------------------------------------------
// 1st and 2nd 5 pin connectors on back in FACING order
// when seen from front of board.  Note that a single
// 15 pin connector on the board is used for 3 5 pin plugs.

#define PIN_BUTTON_IN0      29      // pin 5 on 1st connector facing
#define PIN_BUTTON_IN1      30      // pin 4
#define PIN_BUTTON_IN2      31      // pin 3
#define PIN_BUTTON_IN3      32      // pin 2
#define PIN_BUTTON_IN4      33      // pin 1

#define PIN_BUTTON_OUT4     28      // pin 1 on 2nd connector facing
#define PIN_BUTTON_OUT3     27      // pin 2
#define PIN_BUTTON_OUT2     26      // pin 3
#define PIN_BUTTON_OUT1     25      // pin 4
#define PIN_BUTTON_OUT0     24      // pin 5


//--------------------------------------------------------
// Expression pedal connector, 6 pin dupont on front, facing
//--------------------------------------------------------
// I added 10K resistors to the 1/4" pedal jacks to
// the insertion switch to ground them when not in use.
// New PCB also adds 10K pulldowns to each as well as a
// 1K inline power resistor to prevent reboots when inserting
// expression pedal plugs, resulting in an effective range of
// about 0..(0.75 * 1023)
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

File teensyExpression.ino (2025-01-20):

// teensyExpression.ino


#include <myDebug.h>
#include "src/prefs.h"
#include "src/myTFT.h"
#include "src/myLeds.h"
#include "src/pedals.h"
#include "src/rotary.h"
#include "src/buttons.h"
#include "src/expSystem.h"
#include "src/myMidiHost.h"
#include "src/fileSystem.h"


#define TOUCH_DRAW_TEST  0

#if TOUCH_DRAW_TEST
    #include "src/myTouchScreen.h"
#endif

//-----------------------------------------------------------
// setup
//-----------------------------------------------------------


extern "C" {
    extern void setFishmanFTPDescriptor();
    extern void my_usb_init();          // in usb_dev.c
}


void setup()
{
    bool prefs_reset = init_global_prefs();

    // turn off myDebug output and
    // start the SERIAL_DEVICE (before USB is started)

    dbgSerial = 0;
    SERIAL_DEVICE.begin(115200);
    elapsedMillis serial_started = 0;
    while (serial_started<1000 && !SERIAL_DEVICE) {}

    #if 1
        if (SERIAL_DEVICE)
        {
            delay(1000);
            SERIAL_DEVICE.println("hello from teensyExpression.ino() setup() " TEENSY_EXPRESSION_VERSION " SERIAL_DEVICE port");
        }
    #endif

    // if the DEBUG_PORT is set to serial, we can start myDebug now

    uint8_t debug_device = getPref8(PREF_DEBUG_PORT);
    if (debug_device == DEBUG_DEVICE_SERIAL)
    {
        dbgSerial = &SERIAL_DEVICE;
    }


    //------------------------------------------
    // start the USB device
    //------------------------------------------

    if (getPref8(PREF_SPOOF_FTP))
        setFishmanFTPDescriptor();
    my_usb_init();
    delay(1000);

    // start the USB Serial port

    Serial.begin(115200);
    serial_started = 0;
    while (serial_started<1000 && !Serial) {}
    delay(400);

    // and if the pref is DEBUG_DEVICE_USB
    // set it into myDebug

    if (debug_device == DEBUG_DEVICE_USB)
    {
        dbgSerial = &Serial;
    }

    display(0,"teensyExpression,ino " TEENSY_EXPRESSION_VERSION " setup() started",0);

    //-------------------------------------------------
    // start the TFT display device
   //-------------------------------------------------

    initMyTFT();

    mylcd.setTextBackColor(0);
    mylcd.setTextColor(TFT_WHITE);
    mylcd.setFont(Arial_16);
    mylcd.setCursor(5,5);
    mylcd.print("teensyExpression ");
    mylcd.print(TEENSY_EXPRESSION_VERSION);
    mylcd.println(" started ... ");

    int do_delay = 2000;
    mylcd.setTextColor(TFT_YELLOW);

    if (prefs_reset)
    {
        const char *msg = "    PREFS WERE AUTOMATICALLY RESET!!";
        warning(0,"%s",msg);
        mylcd.println(msg);
        do_delay = 5000;
    }
    if (!dbgSerial)
    {
        const char *msg = "    NO SERIAL PORT IS ACTIVE!!";
        warning(0,"%s",msg);
        mylcd.println(msg);
        do_delay = 5000;
    }
    else if (debug_device == DEBUG_DEVICE_SERIAL)
    {
        const char *msg = "    DEBUG_OUTPUT to hardware SERIAL_DEVICE!";
        warning(0,"%s",msg);
        mylcd.println(msg);
        do_delay = 5000;
    }

    #if !defined(USB_MIDI4_SERIAL)
    {
        const char *msg = "    NOT COMPILED WITH USB_MIDI4_SERIAL !!!";
        my_error("%s",msg);
        mylcd.println(msg);
        do_delay = 5000;
    }
    #endif


    //--------------------------------------
    // start the file system
    //--------------------------------------

	uint8_t fs_device = getPref8(PREF_FILE_SYSTEM_PORT);
    warning(0,"FILE_SYS_DEVICE %s",
		fs_device == FILE_SYS_DEVICE_SERIAL ? "is SERIAL" :
		fs_device == FILE_SYS_DEVICE_USB 	? "is USB" :
		debug_device == DEBUG_DEVICE_SERIAL 	? "follows DEBUG_DEVICE which is SERIAL" :
		debug_device == DEBUG_DEVICE_USB 		? "follows DEBUG_DEVICE which is USB" :
		"follows DEBUG_DEVICE which is OFF" );

	if (!initFileSystem())
	{
        const char *msg = "    COULD NOT START FILE SYSTEM!!";
        my_error("%s",msg);
        mylcd.println(msg);
        do_delay = 10000;
	}
    else
    {
        mylcd.setTextColor(TFT_WHITE);
        mylcd.println("File System Started OK");
    }

    delay(do_delay);

    // start myMidihost
    // and the rest of the stuff

    midi_host.init();

    display(0,"initializing system ...",0);

    initLEDs();
    LEDFancyStart();
    clearLEDs();
    showLEDs();

    theSystem.begin();

    display(0,"system running ...",0);

}   // setup()




//-----------------------------------------
// loop
//-----------------------------------------

void loop()
{
    freeFileCommands();
    theSystem.updateUI();
}

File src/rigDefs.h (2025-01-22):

//----------------------------------
// rigDefs.h
//----------------------------------
// defines channels and CC numbers used on iPad

#pragma once

//----------------
// synth
//----------------

#define SYNTH_PROGRAM_CHANNEL       7       // 1 based

#define SYNTH_VOLUME_CHANNEL        1
#define SYNTH_VOLUME_CC             7


//----------------
// toneStack
//----------------

#define GUITAR_EFFECTS_CHANNEL  			9   // one based

#define GUITAR_WAH_CONTROL_CC              11
// #define GUITAR_REVERB_DEPTH_CC             20

#define GUITAR_DISTORTION_EFFECT_CC        26
#define GUITAR_WAH_EFFECT_CC               27
#define GUITAR_FLANGER_EFFECT_CC           28
#define GUITAR_CHORUS_EFFECT_CC            29
#define GUITAR_ECHO_EFFECT_CC              30

#define GUITAR_VOLUME_CHANNEL               7       // one based
#define GUITAR_VOLUME_CC                    7
    // not used in new rig

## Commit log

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2020-05-26 broke out teensyExpressionTezt ... swithed to MIDI+SERIAL (COM7)
    [teensyExpression.ino]
2020-05-30 WORKING BUT BUSTED SCREEN - added Serial2 to teensyPi and Serial3 to Expression Pedal
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2020-06-07 PIN ASSIGNMENTS RESOLVED - created expressionPedals.h & cpp
    [teensyExpression.ino]
2020-06-07 CLEANUP - revert to ILI9341_t3 master, rename TouchScreen to myTouchscreen remove unused rotaryIRQ code
    [teensyExpression.ino]
2020-06-07 a little cleanup - removed "m_loop_event_cleared" kludge, added room in rawButton m_event_state to replace it on the lookout for the anomoly that made me kludge it in the first place
    [rawButtonArray.cpp]
2020-06-09 INITIAL CURVES Broke out systemConfig into it's own source files. Added experimental "rotary brightness curve" Created preliminary "curve" editor
    [rotary.cpp]
2020-06-10 initial system configuration
    [systemConfig.txt, zobs_systemConfig.cpp.txt, zobs_systemConfig.h.txt]
2020-06-10 added REBOOT button and flashing red light when rebooting
2020-06-12 working on FTP host mode ... general cleanup too.
    [systemConfig.txt, zobs_systemConfig.cpp.txt, zobs_systemConfig.h.txt]
2020-06-16 MIDI HOST DIRECT INTERRUPT PASS THROUGH I need some time to think about how to proceed from here. - try to spoof FTP editor again? - try to measure event timing and see if I can play the guitar with 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
2020-06-16 effing checking in head with unresolved issues
    [defines.h, teensyExpression.ino]
2020-06-16 fixed spellings, removed a debug println
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2020-06-20 reworked BUTTON handling ... now includes LEDs (colors) and repeat funcitonality
    [buttons.cpp]
2020-06-21 start FTP_MIDI_SPEC
    [FTP_MIDI_SPEC.xlsm]
2020-06-21 changed dbgSerial to a pointer to a Stream allow for diverting output from myDebug to other hardware serial devices on teensy
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2020-06-23 implemented LCDWIKI_KBV::dim() which is basically not fast enough to use note that I have ili9486 SPI modules (from rPi) but don't know if they will be faster even if I get Paul's DMA stuff to work w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
2020-06-23 added Factory Reset cleaned up includes of EEPROM.h
    [defines.h]
2020-06-23 moved my stuff to LCDWIKI_GUI_prh.cpp added param to printJustified replaced LCDWIKI_GUI::text_mode with m_use_bc cleaned up comments
    [teensyExpression.ino]
2020-06-23 implemented modal windows and m_flags on expWindow added param to expWindow::begin() for coming down the stack added yesNoDialog and used it in configSystem FactoryReset touched all printJustified() 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
2020-06-23 made global patch system button that calls ftpTuner <--> ftpSensitivity as modal dialogs
2020-06-23 PATCHES ARE RESPONSIBLE FOR SAVING BUTTON STATE in end() if they are going to use it to store data!
2020-06-25 proof of concept - FTP on remote device tested with MidiOx routing
2020-06-25 initial changes to bump teensy to 2 cables and rough out midi monitor
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2020-06-25 dialog consistency - added and/or use GREEN pad button to go back
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2020-06-27 CONFIG_PEDALS - added CALIBRATION, MIN and MAX value x offsets better overall display
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2020-06-29 fixes during early alpha ipad test had to change device id - no way to re-enumerate on ipad
2020-06-30 FTP Checksum and patch display, Standard Midi CCs, more FTP/analysis begin newRig design.
    [hardware_patches.csv]
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2020-07-13 Final initial "SET PEDAL POSTION" algorithm. velocityTest sucks. PIDTest sort of works. See notes in PIDTest.
2020-07-13 FINAL INITIAL PEDAL Arduino/autoPedal.ino (teensyExpresion/test/PIDTest.ino and comTest.ino) acts decently as remote to teensy based on the two routines teesnySendByte() and teensyReceiveByte. Copied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
2020-07-14 AFTER DEBUGGING PEDAL CIRCUIT BOARD NEED TO CHANGE EXPR BOX PEDAL CIRCUITS!! so there is a 1K resistor on the power, and the rest are just switches to ground.
2020-07-18 WRAPPING UP PEDAL (disatisfied) DOES MOVES & AUTO CALIBRATE FORCE IS TOO WEEK FOR SPRINGY DOES NOT DO DETENTS YET
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2020-08-13 FRAMEWORK FOR LOOPER RELATIVE VOLUMES and MONO_MODE SYNTH volumes also moved ftp_poly and bend modes to ftp.cpp and got rid of fast button to ftp tuner/sensitivity
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2020-09-19 FIRST INTEGRATED LOOPER AND TEENSY-EXPRESSION TEST Here on the teensyExpression and teensyPi side teensyPi now recognizes my "midi packets" coming in over the Serial2 port from the teensyExpression, 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
2020-09-30 reworked patchNewRig to remove dependency on button state
    [buttons.cpp]
2020-10-03 fix old rig non-serial loop pedal
    [pedals.cpp]
2020-10-03 RESTRUCTURE FOR GOING PUBLIC - removed my old teensyExpression "ftp_analysis" folder - added previous "public" design folders - created myDebugPrivate for non-public stuff
    [2020-05-19-MidiPedal1 v12.f3d, FTP_MIDI_SPEC.xlsm, back.3mf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]
2020-10-03 made fusion into separate repository
    [2020-05-19-MidiPedal1 v12.f3d, back.3mf, back.stl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]
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2020-10-13 cleaned up BUTTONS (no more groups, radios, or intimate use of state) cleaned up H files - got rid of oldRig, changed newRig to LooperRig added rigBase for use by songMachine fixed minor bugs due to 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
    [buttons.cpp, defines.h]
2020-10-14 quick_mode now only takes over top 4x4 buttons - can still use looper, songmachine, etc, in quick mode
2020-10-14 2nd PROOF OF CONCEPT (Beta Candidate) quick_mode leaves other buttons (col4 and row4) active added ABORT_RECORDING to long click ERASE_TRACK added winFTPTuner & swapModal winFTPSensitivity to short c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
    [teensyExpression.ino]
2020-10-15 fixed MUTE buttons not refreshing when changing tracks
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2020-11-08 fixed crude search for buttons ...
2023-08-04 docs - add new fusion .f3z design
    [teensy_params.csv]
2023-08-04 docs - add new kicad boards and schematics
    [host_board.kicad_pcb, host_board.sch, mother_board.kicad_pcb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]
2023-08-04 docs - restructure
    [FTP_MIDI_SPEC.xlsm, hardware_patches.csv]
2023-08-04 docs - add new fusion STL exports and prusa 3MF files
    [back.3mf, back.stl, base1.3mf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]
2023-08-04 Fixed #elser, added TEENSY_EXPRESSION_VERSION to startup display and config "System" menu item
    [defines.h, teensyExpression.ino]
2023-08-20 docs/kicad - added new display_connector, reworked tentative new PCB
    [mother_board.kicad_pcb, uno_display_connector.kicad_pcb, uno_display_connector.sch]
2023-08-20 start MAKE NEW motherboard and display_connector FOR olds TeensyExprssion box with TE2 code
    [mother_board.kicad_pcb, mother_board.sch, uno_display_connector.kicad_pcb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]
2023-08-21 kicad - corrected TFT data pin order for new teensyExpression2 board/code
    [mother_board.kicad_pcb, mother_board.sch, uno_display_connector.kicad_pcb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]
2023-08-21 BUILD new combined mother_board and uno_display_connector. PRINT new display_frame.
    [new_display_frame.3mf, new_display_frame.stl, new_display_frame_cover.3mf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]
2023-08-22 AFTER BUILD NEW PCBs - corrected display connector pins; removed old combined plot and gcode file
    [mother_board.kicad_pcb, mother_board.sch, uno_display_combined.kicad_pcb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]
2023-08-23 AFTER TE2 REBUILD - new gcode for left, top, and back. Corrected symbols for Serial Connector (and on motherboard)
    [back.3mf, mother_board.sch, serial_connector.sch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]
2023-08-23 added 1K resistor to pedal power to keep from crashing while inserting plugs
    [mother_board.kicad_pcb, mother_board.sch]
2023-08-24 fixed compiler warnings from new teensyDuino 1.58
    [buttons.cpp]
2023-08-24 NEW MOTHERBOARD PIN DEFINITIONS - updated defines.h and TFT.cpp to use the new motherboard
2023-08-24 fixed minor bug in winConfigPedal.cpp when using BLUE button to change pedals while IN calibration mode
2023-08-25 EEPROM - check/write 237 to EEPROM 0 to identify teensyExpression1 and automatically reset prefs if not
    [prefs.h, teensyExpression.ino]
2023-09-13 updated preferences.txt to try to avoid stomping on teensyPiLooper
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2024-05-13 update all TE preferences.txt to build in /src/ArduinoBuilds for easier clean builds
2025-01-11 REDRAW and REPRINT TeensyExpression Box (silver)
    [back.3mf, back.stl, base1.3mf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]
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2025-01-14 final changes for redrawn, reprinted, and rebuilt teensyExpression box (teensyExpressionRedraw.f3z)
    [base.dxf, teensy_redraw.csv, top_right.3mf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]
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2025-01-14 Manually normalized fileXXXX.cpp & h files between TE1 and TE2 in prep for some bug-fix rework ...
    [defines.h]
2025-01-16 completly reworked COMMON TE1 and TE2 fileXXXX h and cpp and mem_check.cpp files
    [filesSerial.cpp, mem_check.cpp, teensyExpression.ino]
2025-01-17 built and tested new TE Rotary Board
    [rotary_board-B_Cu.gbr, rotary_board-B_Mask.gbr, rotary_board-Edge_Cuts.gbr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]
2025-01-17 recommit unsaved rotary_board.pc ...
    [rotary_board.kicad_pcb]
2025-01-20 print new TE box back
    [back.3mf, back.stl]
2025-01-20 notes regarding resistors for pedals
    [mother_board.kicad_pcb, mother_board.sch]
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2025-01-21 rework prefs, config_system, to try to fix winConfigPedal problems
    [buttons.cpp, prefs.h]
2025-01-21 rework button task(); add re-entrancy protection & simplify debouncing
    [buttons.cpp]
2025-01-21 fix some pedal bugs & cleanup debugging - FIRST SUCCESFUL INTEGRATION TEST
    [pedals.cpp, prefs.h]
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2025-01-22 remove mem_check.cpp issues on teensy4.1
    [mem_check.cpp]
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
